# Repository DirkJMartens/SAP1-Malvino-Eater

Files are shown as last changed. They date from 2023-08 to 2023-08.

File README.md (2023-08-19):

# SAP1-Malvino-Eater
Wire wrapped implementation of Albert Malvino's SAP1 computer, similar to Ben Eater's "8 bit CPU". 

Like thousands of others, I watched Ben Eater's YouTube series on how to "Build an 8-bit CPU from scratch". 
Ben's video series is based on the "SAP-1 (Simple As Possible 1)" computer, described in "Digital Computer Electronics" 
book by Albert Malvino and Jerald Brown, first released in 1977. 

And like thousands of others, I wanted to build my own. Partly to learn a few things, but above all for fun. 
But I also wanted a few differences: 
  - Use wire-wrapping instead of breadboards. As I could only work on it mostly on weekends and in my spare time,
    I wanted it to be longer-lasting so I could put it away easily and pull it out without first spending time to
    find which wires have been dislodged to get it back working again. 
  - Stay closer to Malvino's original design for the SAP-1. 
  - Add some blinkenlights to visualize:
    - LED bar graphs for W-bus, Accu, B-register, Output-register, Instruction register 
    - LEDs for the control signals (La, Ea, Lb, Eb, Ep, CE ...) and the Program Counter 
    - the ring counter indicating the stage of the Fetch/Execute cycle 
    - the instruction decoder 
  - Added a dual 7-segment display to visualize the W-bus content in HEX-format instead of in binary via LED bar graph.

In short, I wanted it to be much more of a visual CPU that can show which signal gets activated and what it triggers 
in various parts of the CPU. Because I wanted the wiring to be visible, I did not use wire-wrap sockets and wire on the 
bottom of the perfboard. Instead, I soldered pin headers next to each row of IC pins so I had access to each pin on the 
top and wire-wrapped from pinheader pin to pinheader pin. 

Most important specs: 
  - 4 bits address bus with 16 bytes RAM memory and an 8 bits data bus 
  - 4 instructions: Load, Add, Sub and Out
  - Opcodes is the most-significant-nibble (top 4 bits) and memory location is the least (bottom 4 bits) 
  - Clock signal can be single stepped, or auto-run with variable clock speed (up to a few dozen Hz)
  - Done using a mix of various 74-series ICs (LS, F ...) and implemented on a 20cmx30cm (8"x12") perfboard.

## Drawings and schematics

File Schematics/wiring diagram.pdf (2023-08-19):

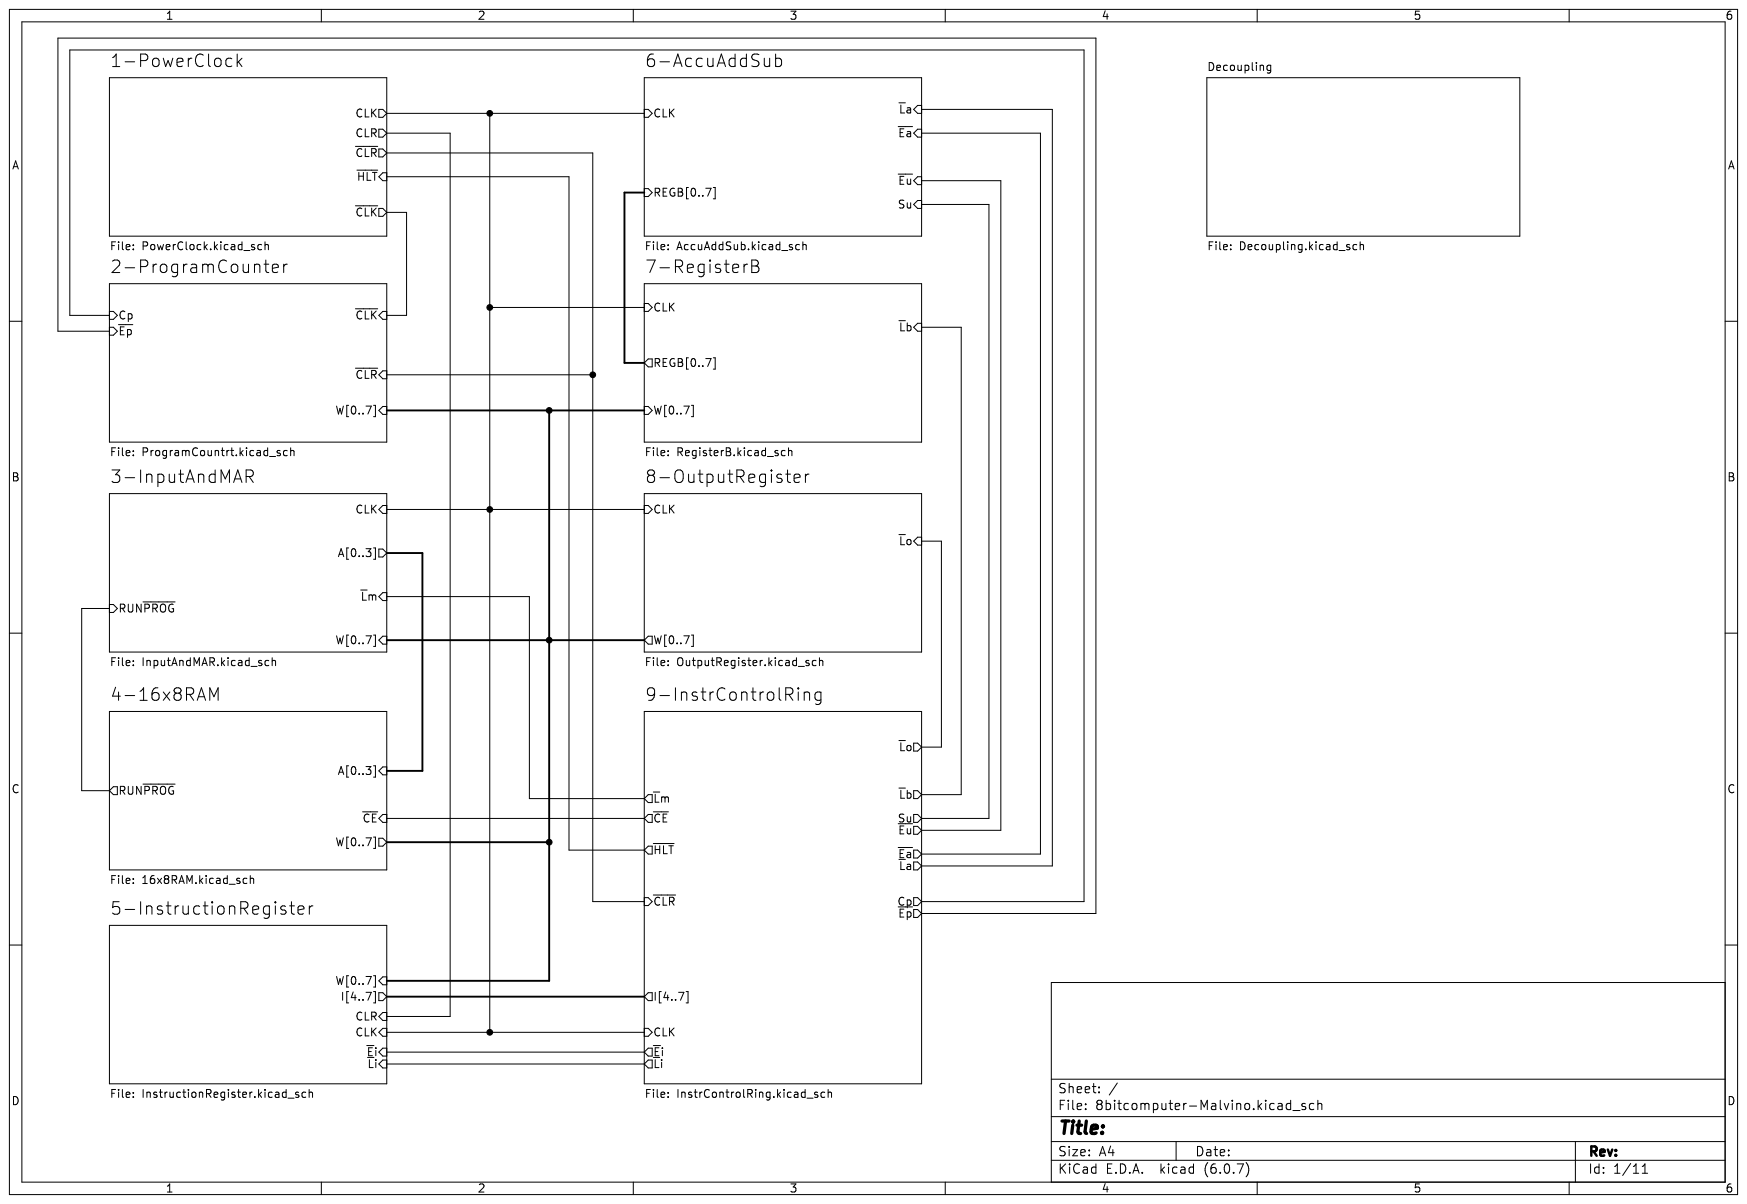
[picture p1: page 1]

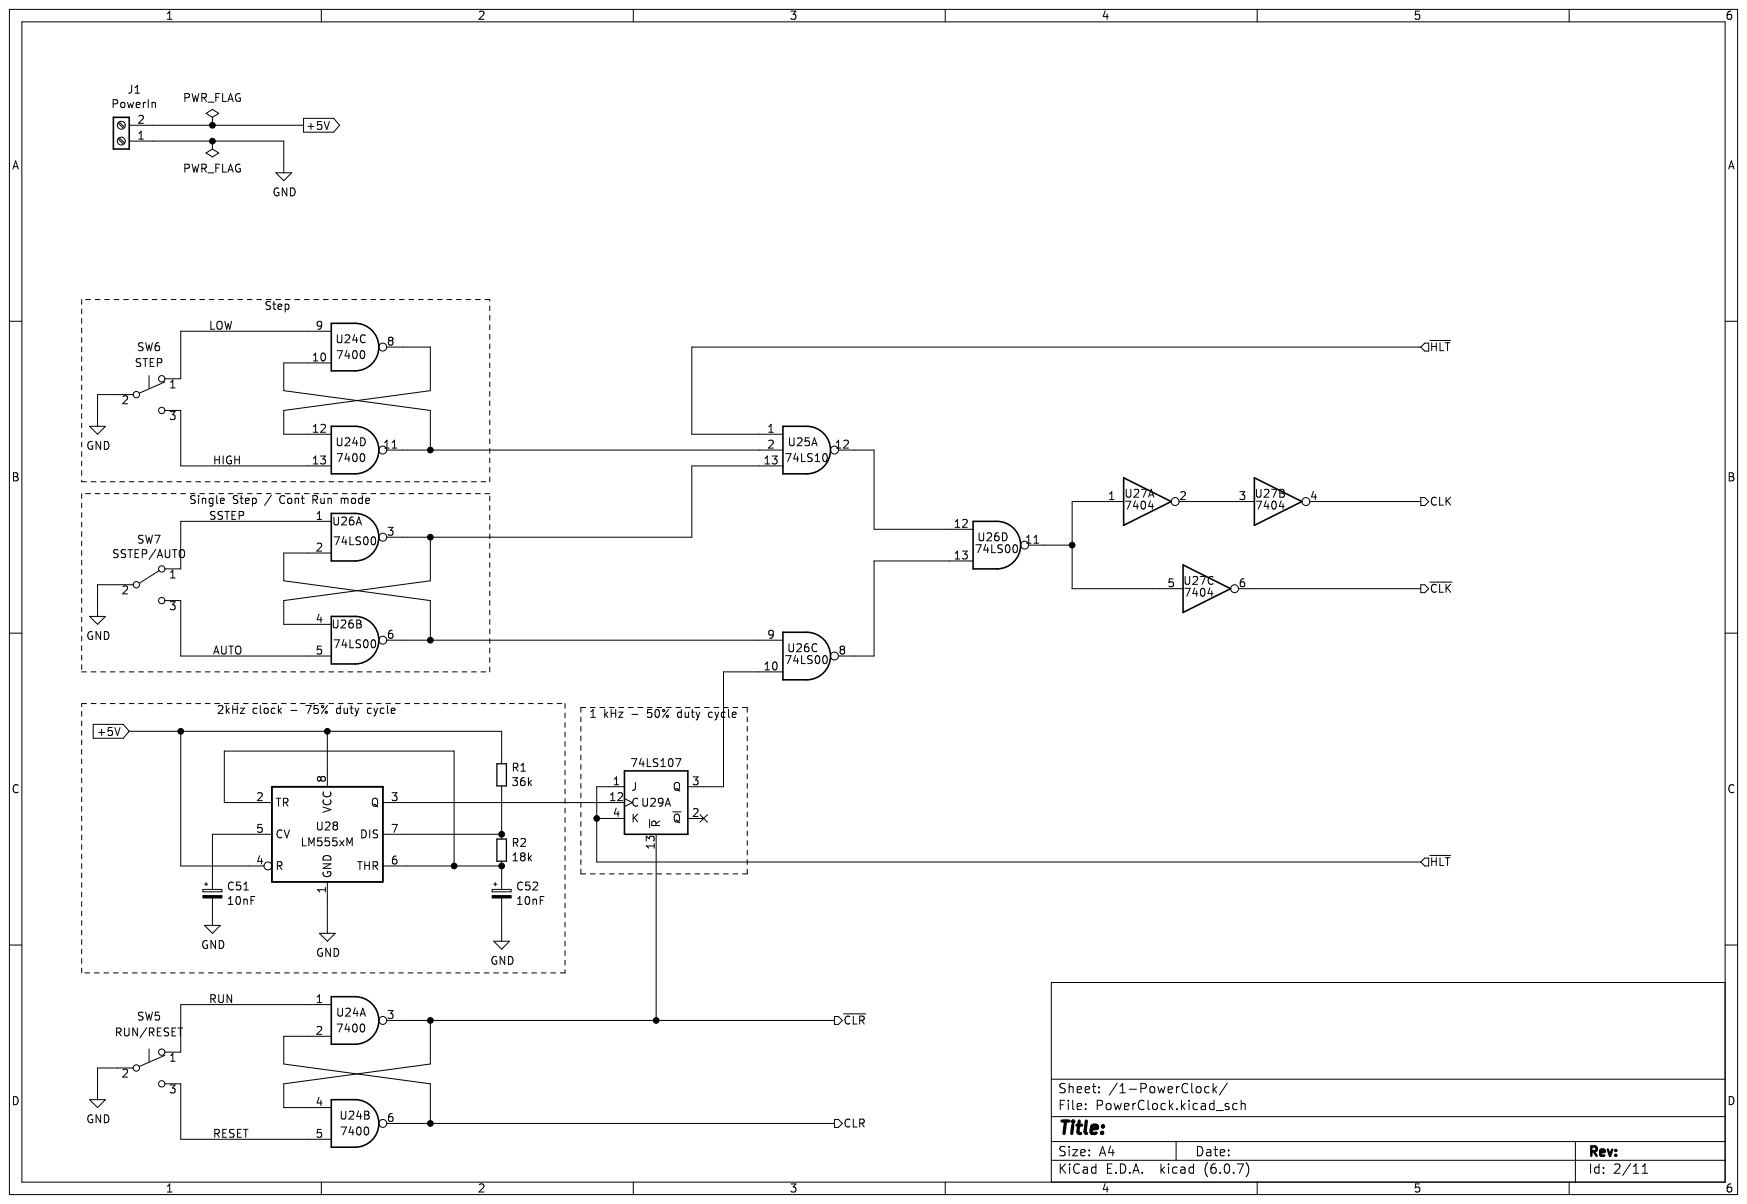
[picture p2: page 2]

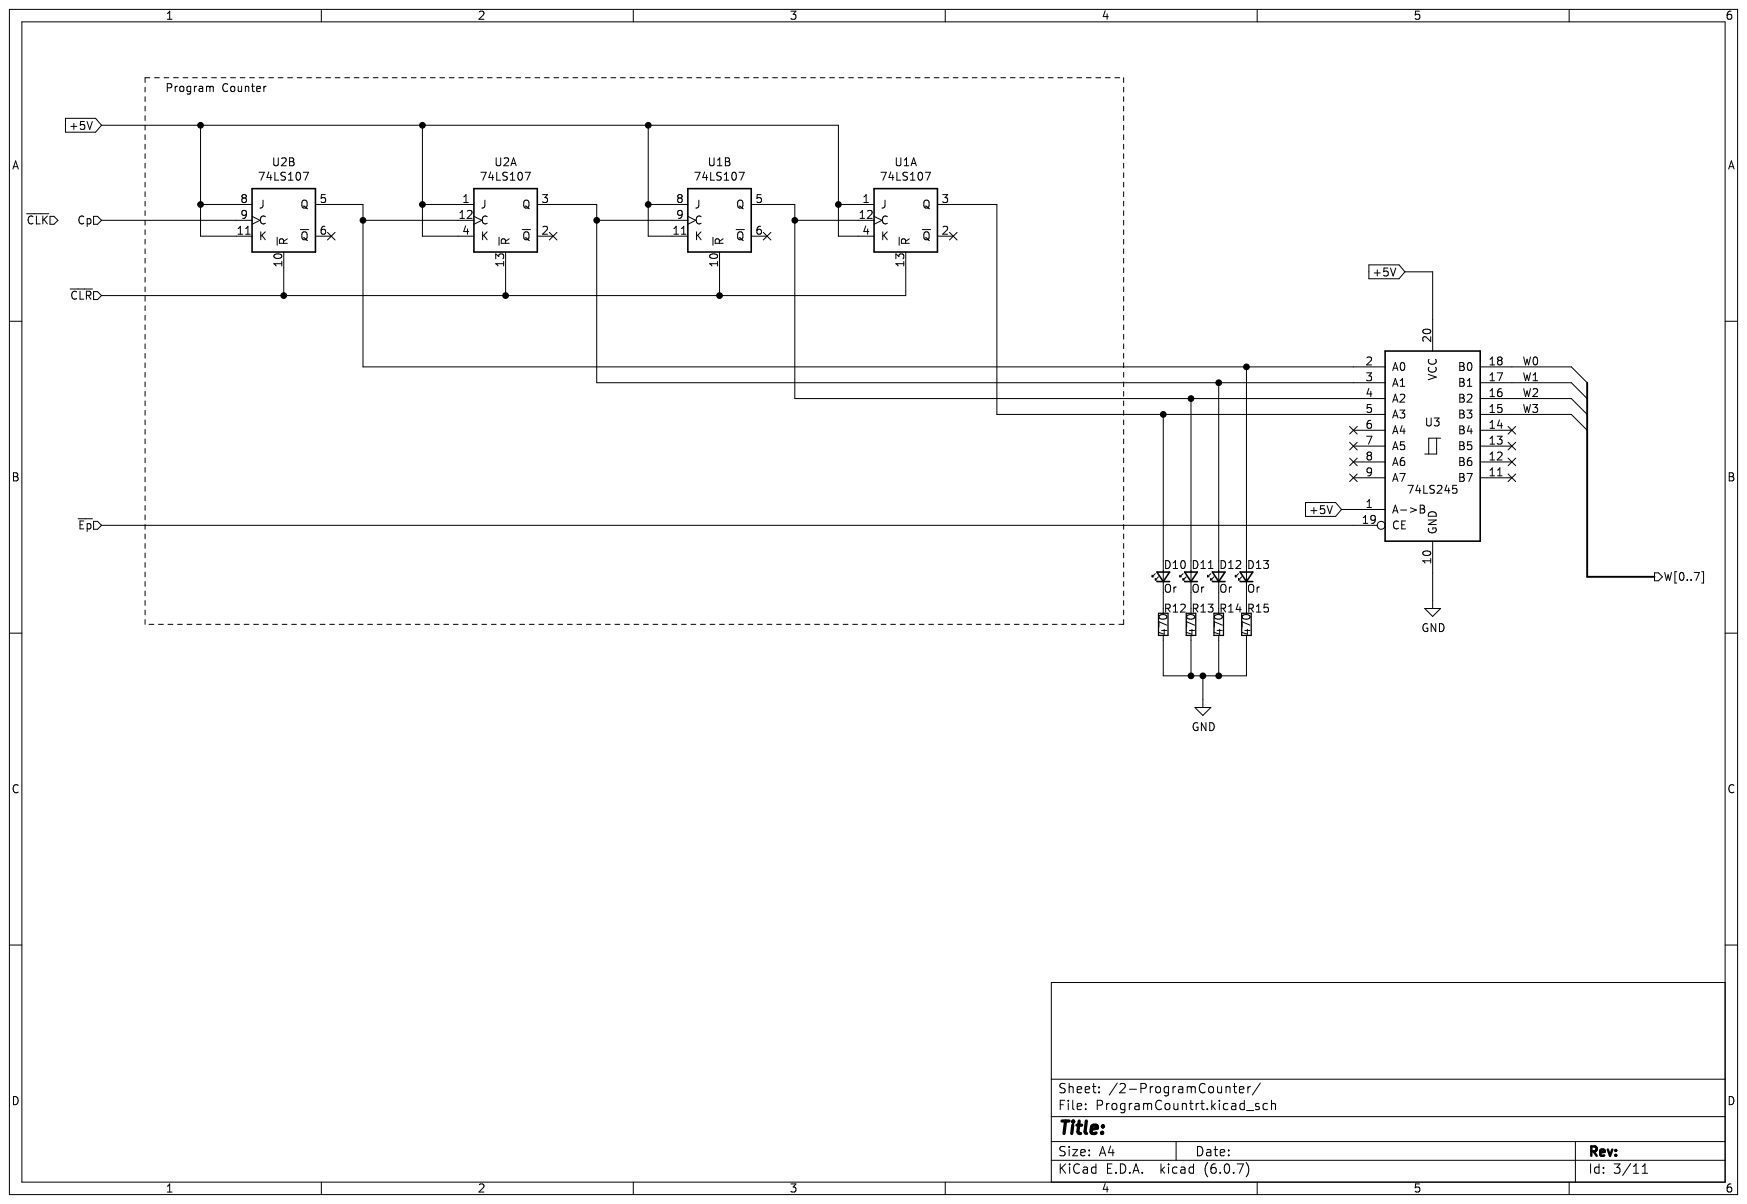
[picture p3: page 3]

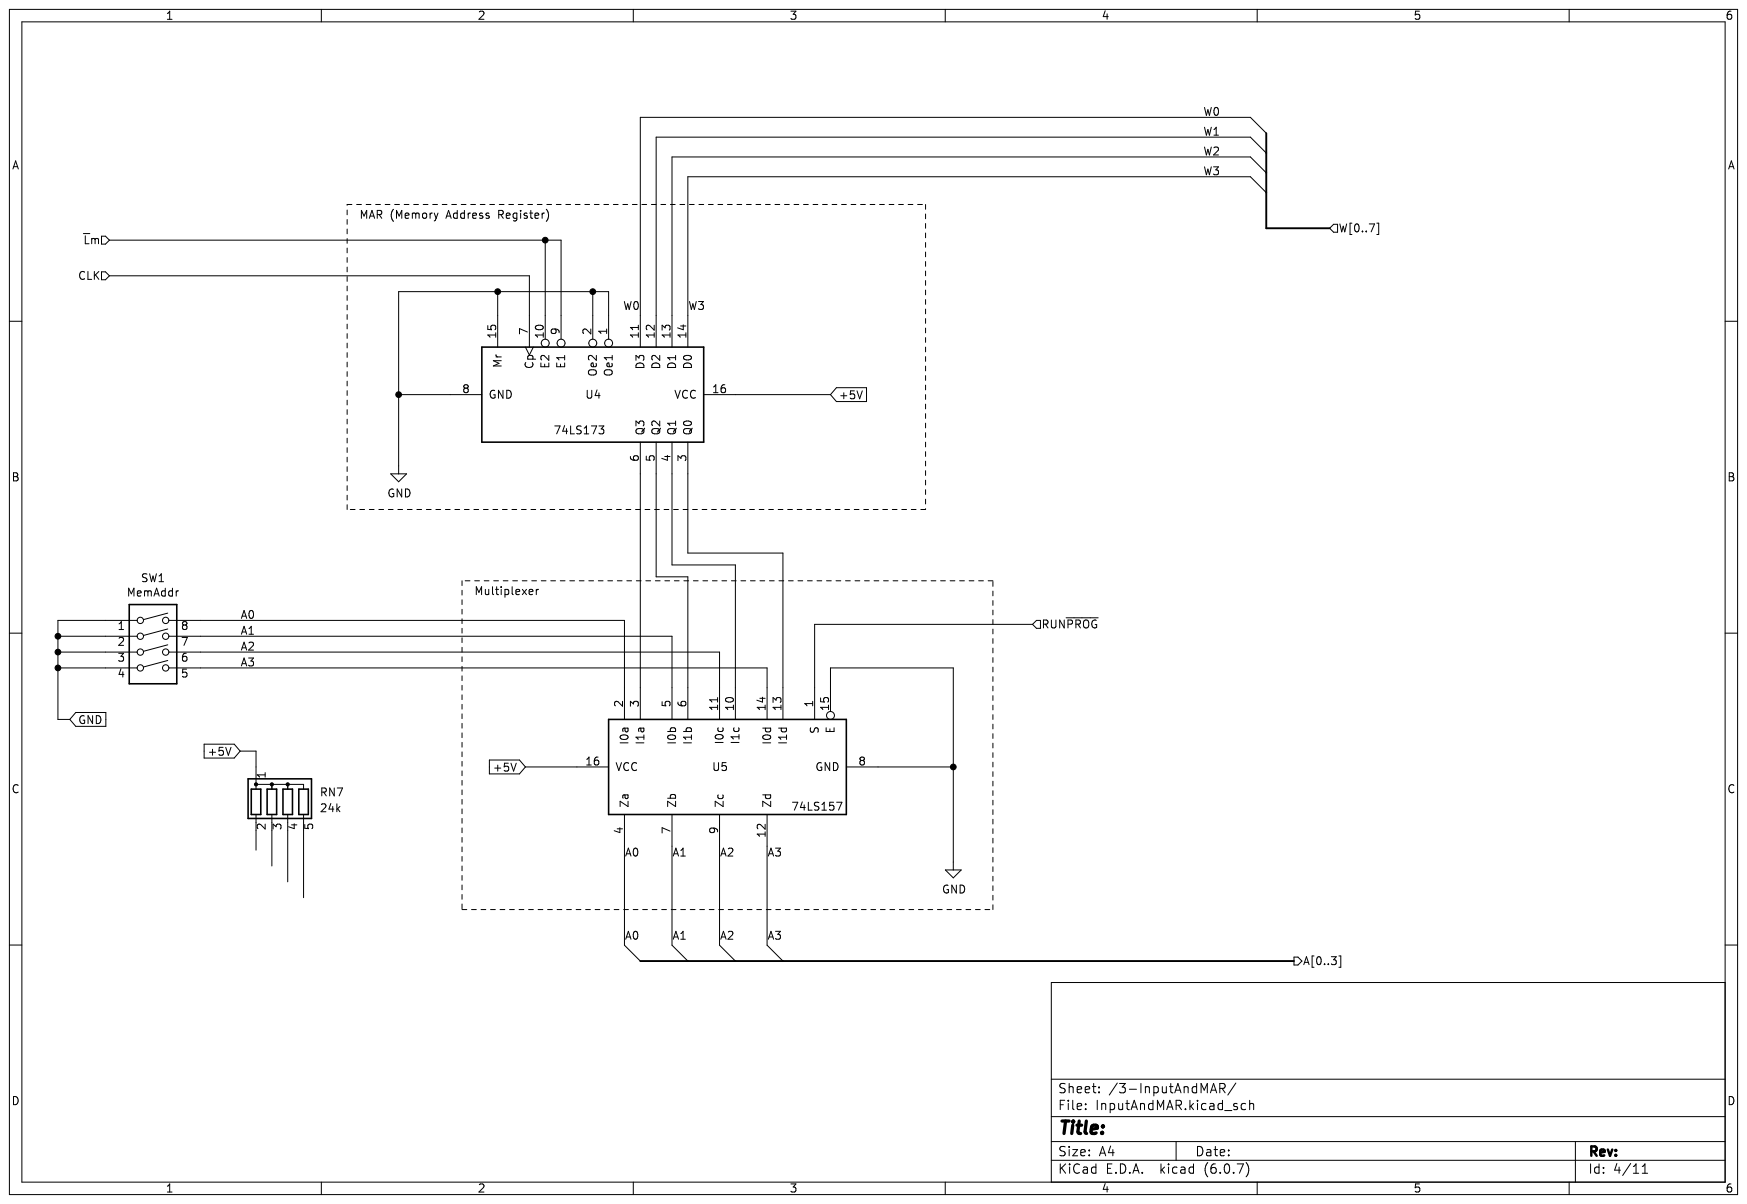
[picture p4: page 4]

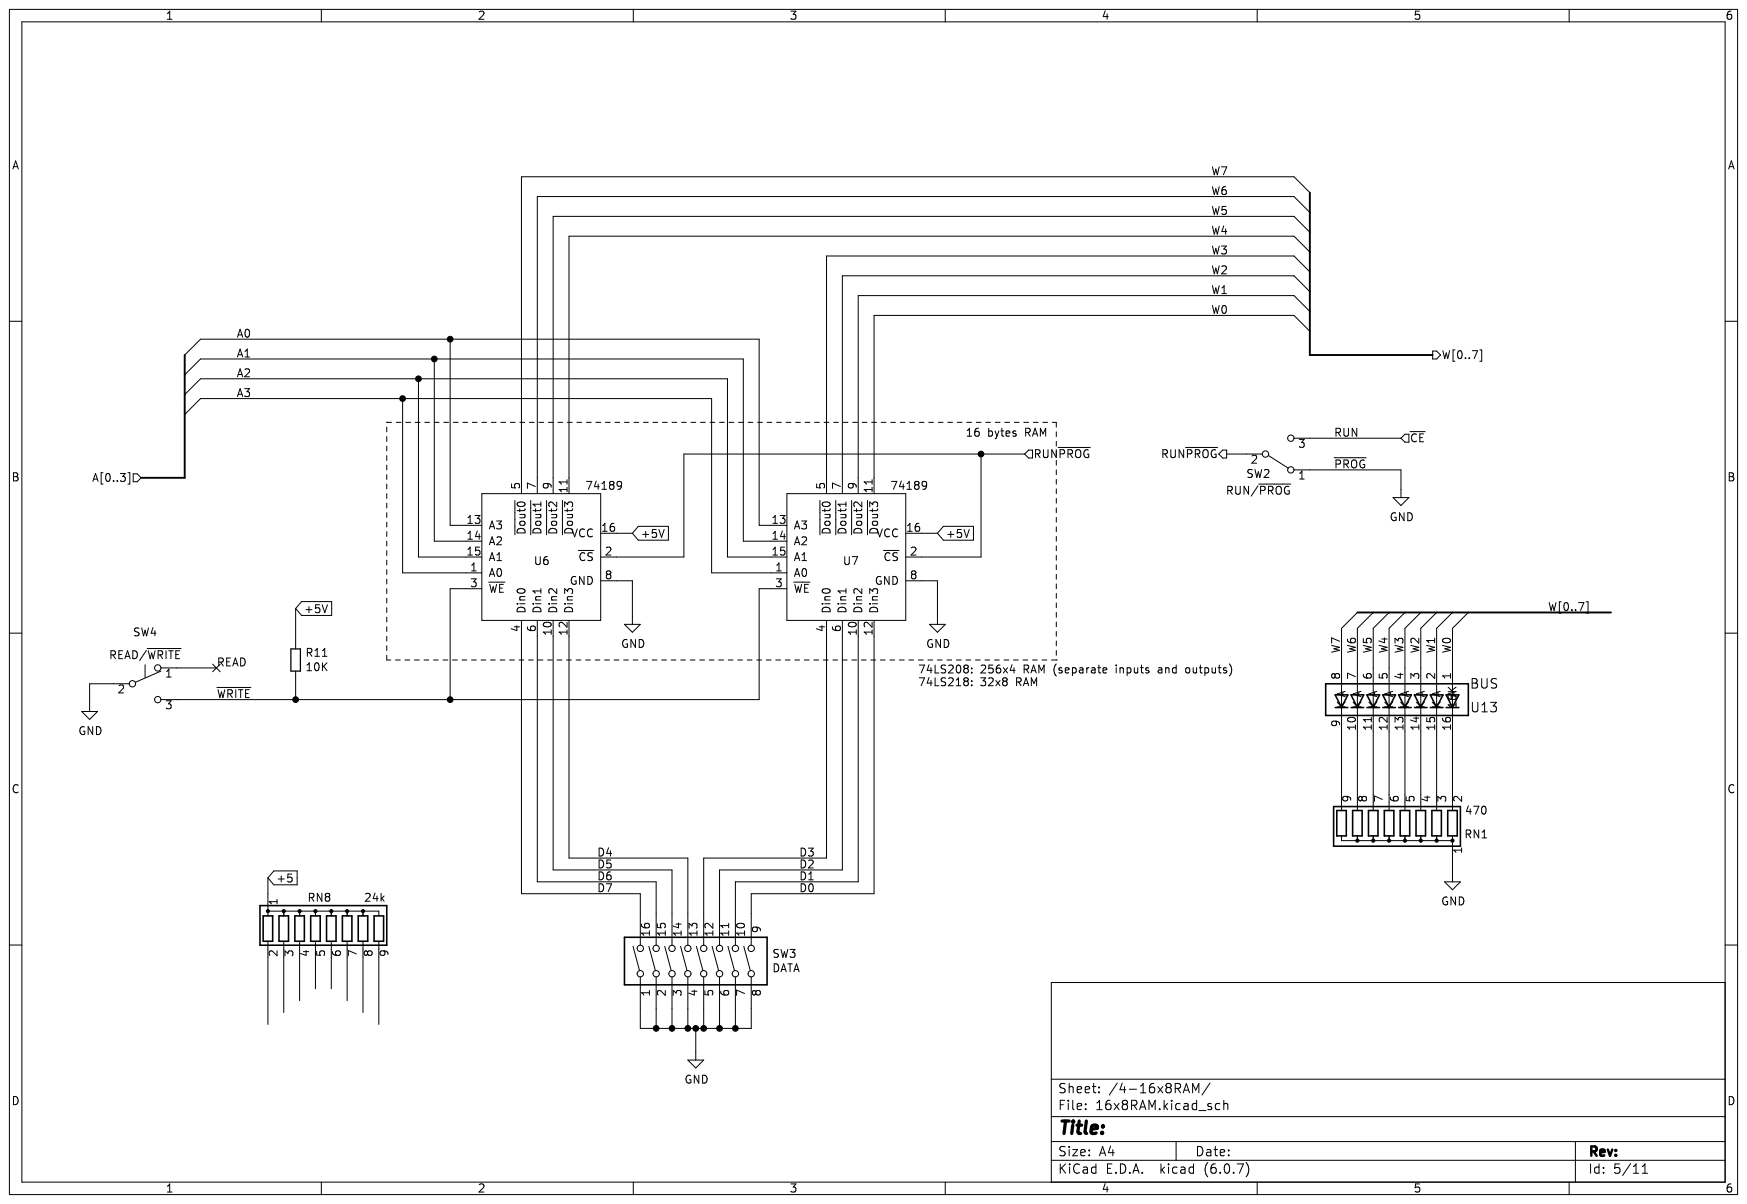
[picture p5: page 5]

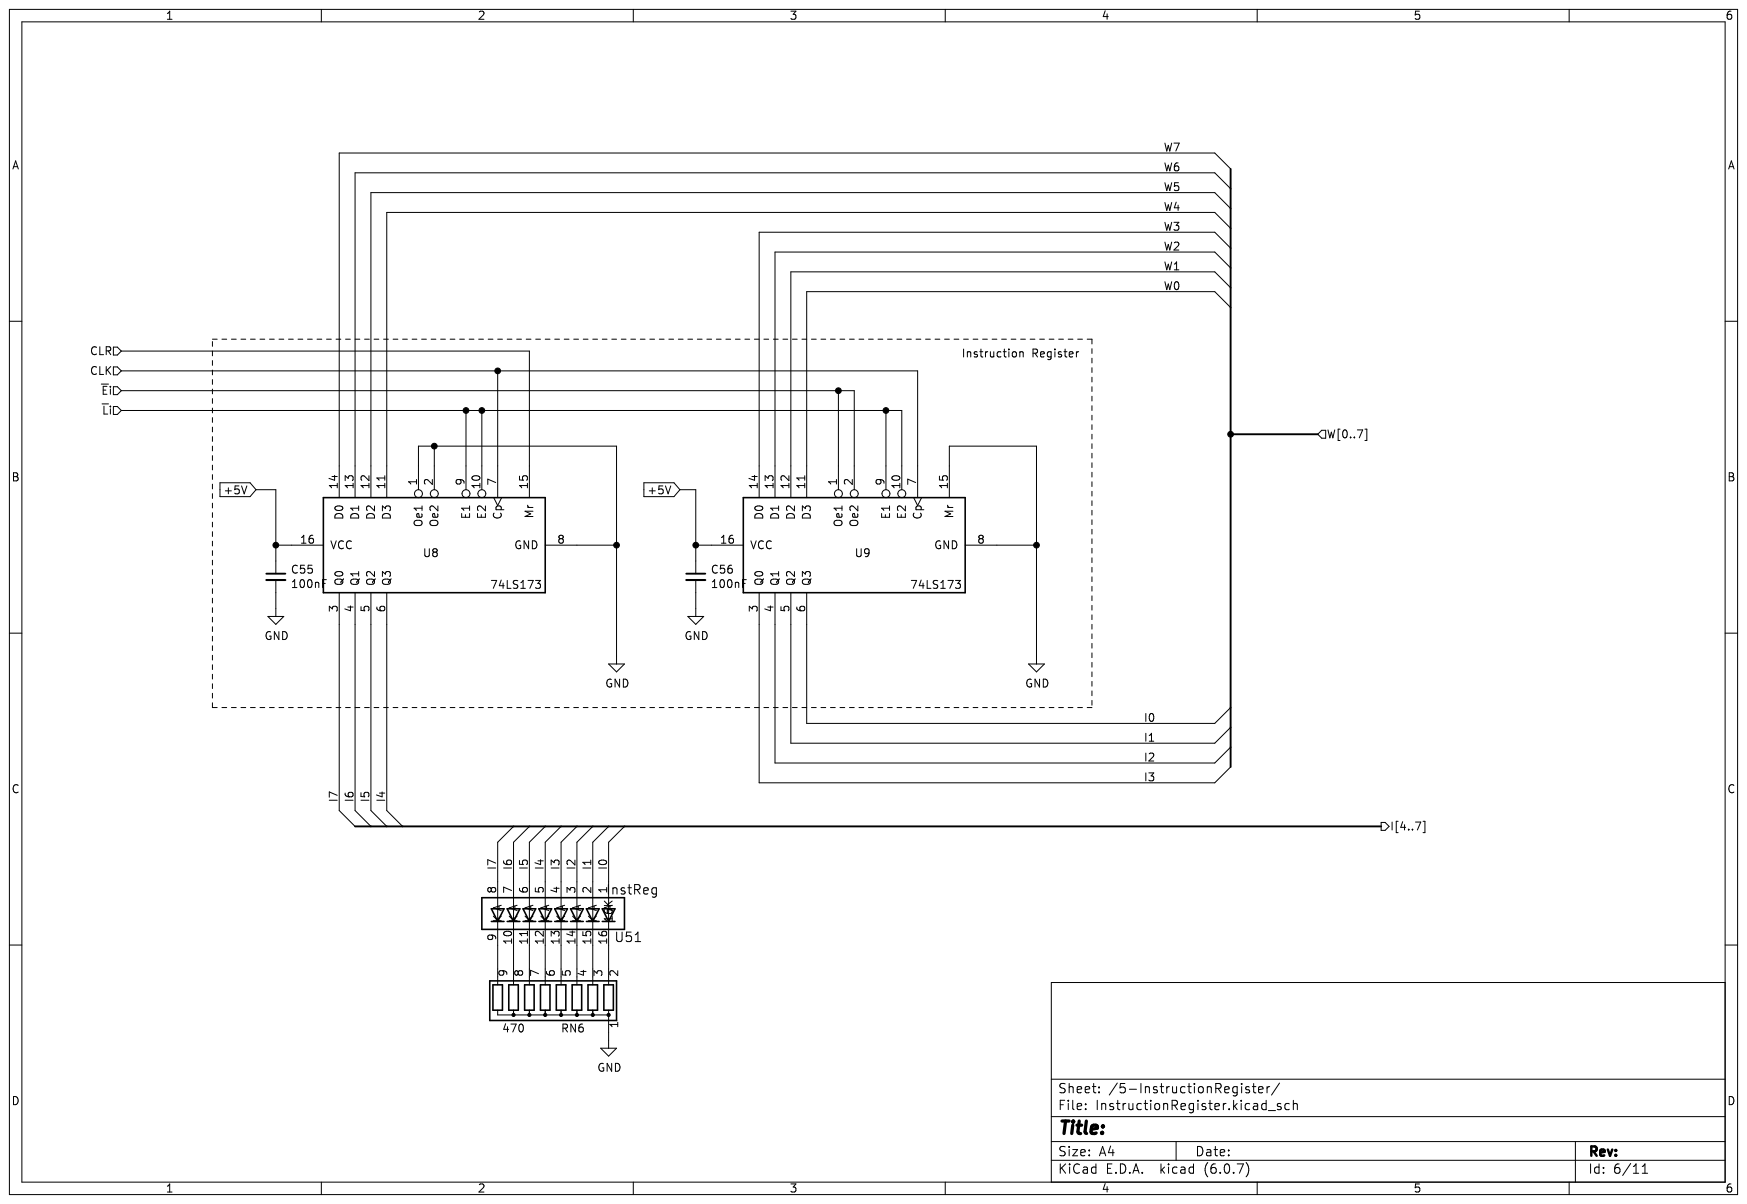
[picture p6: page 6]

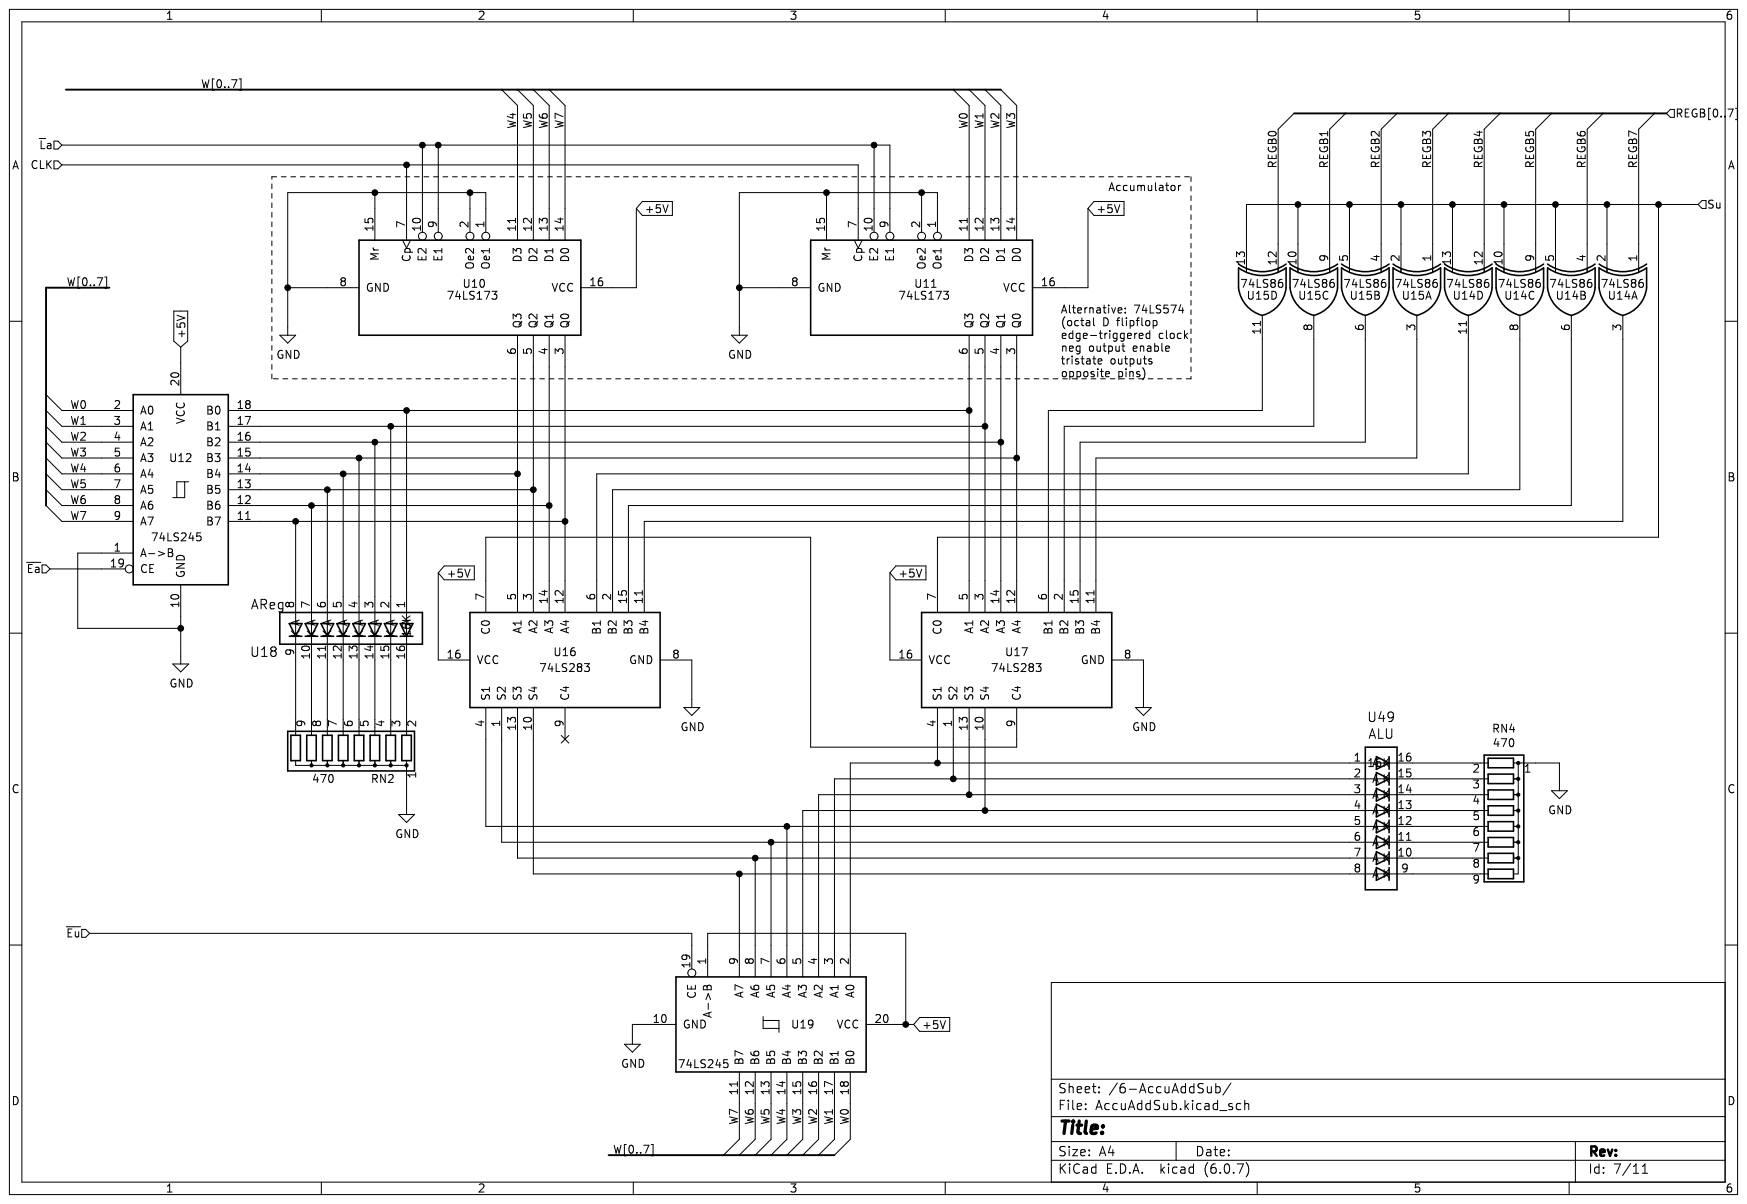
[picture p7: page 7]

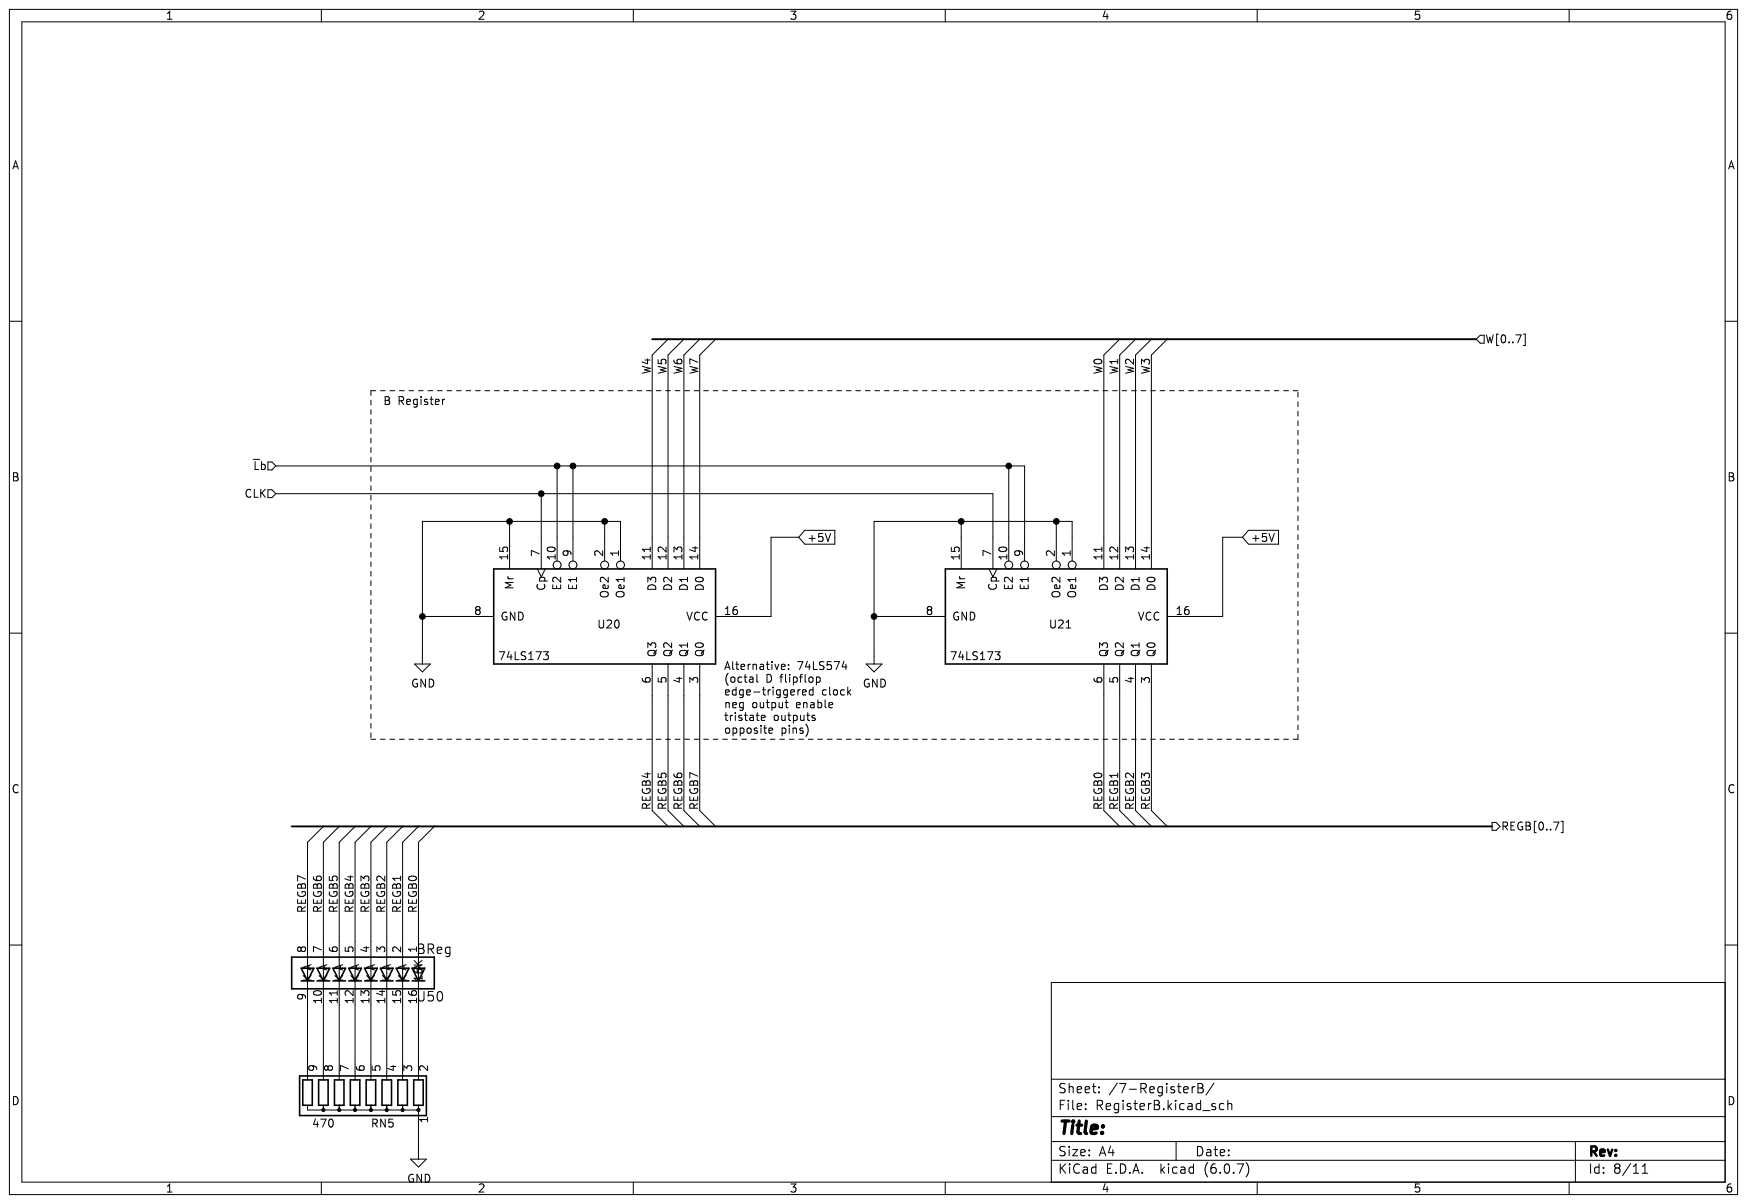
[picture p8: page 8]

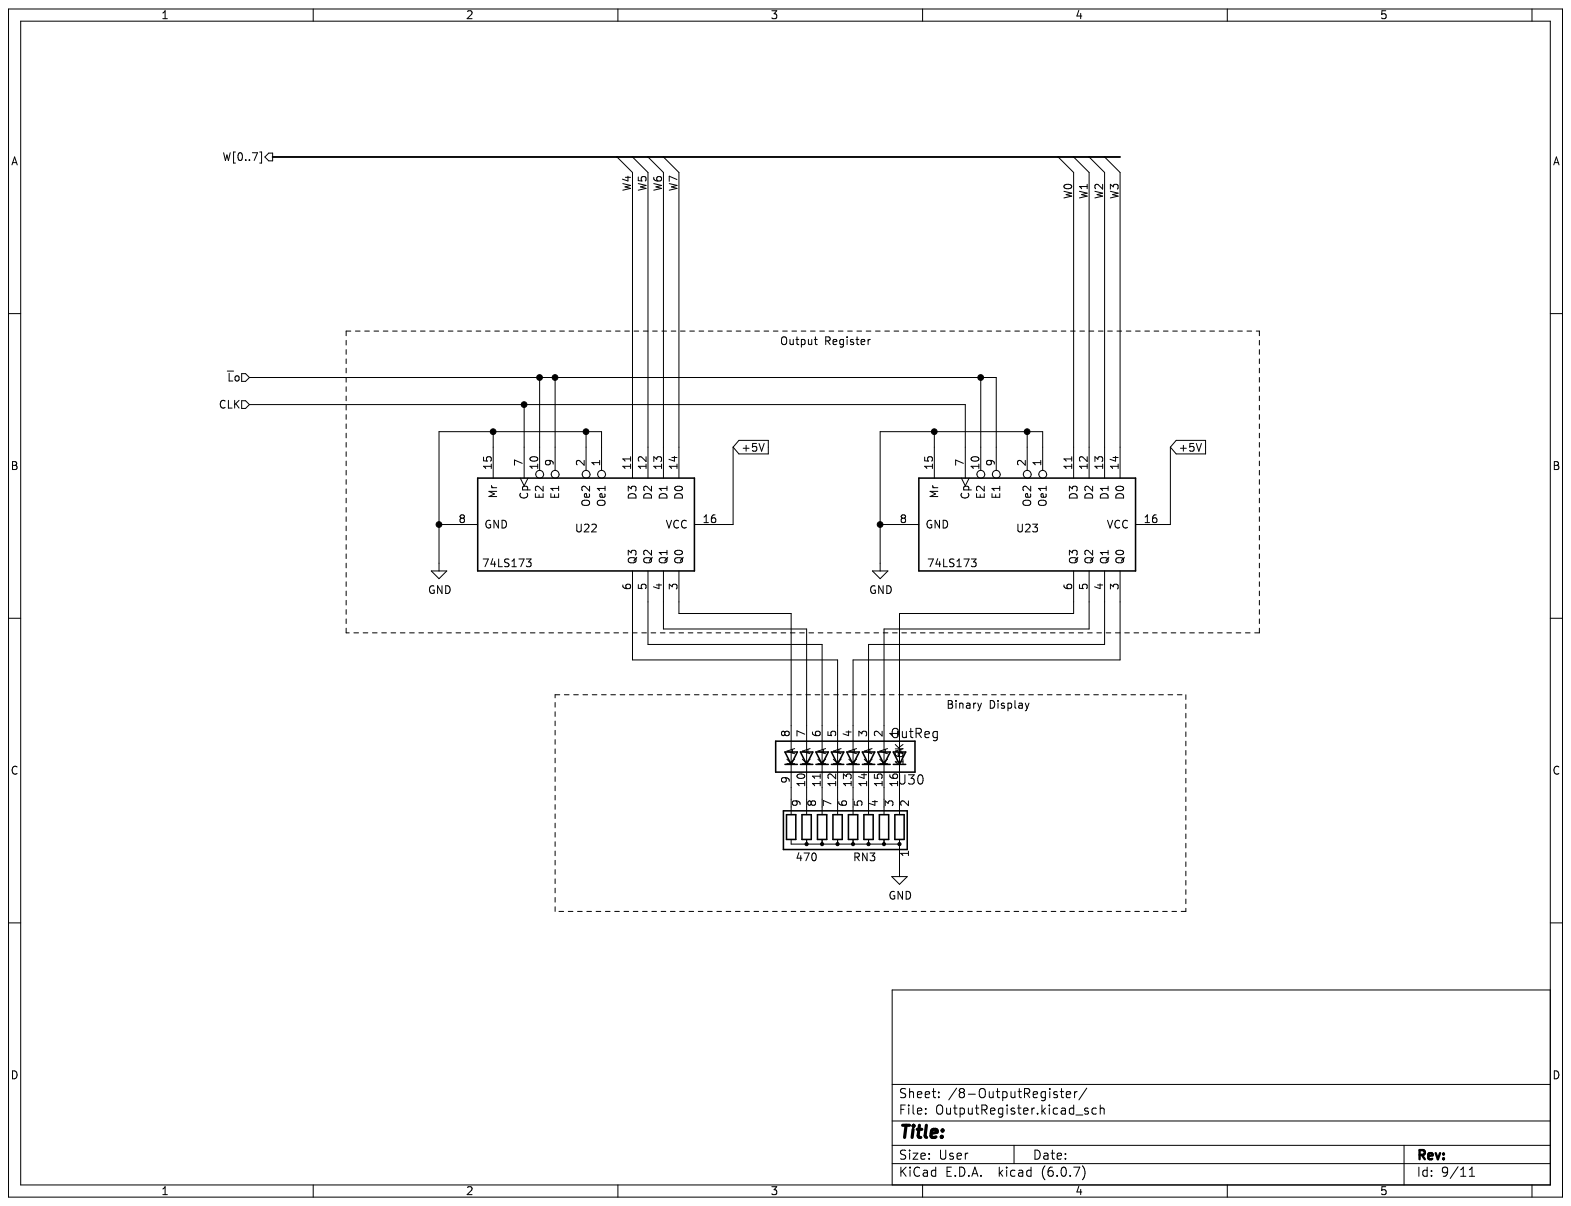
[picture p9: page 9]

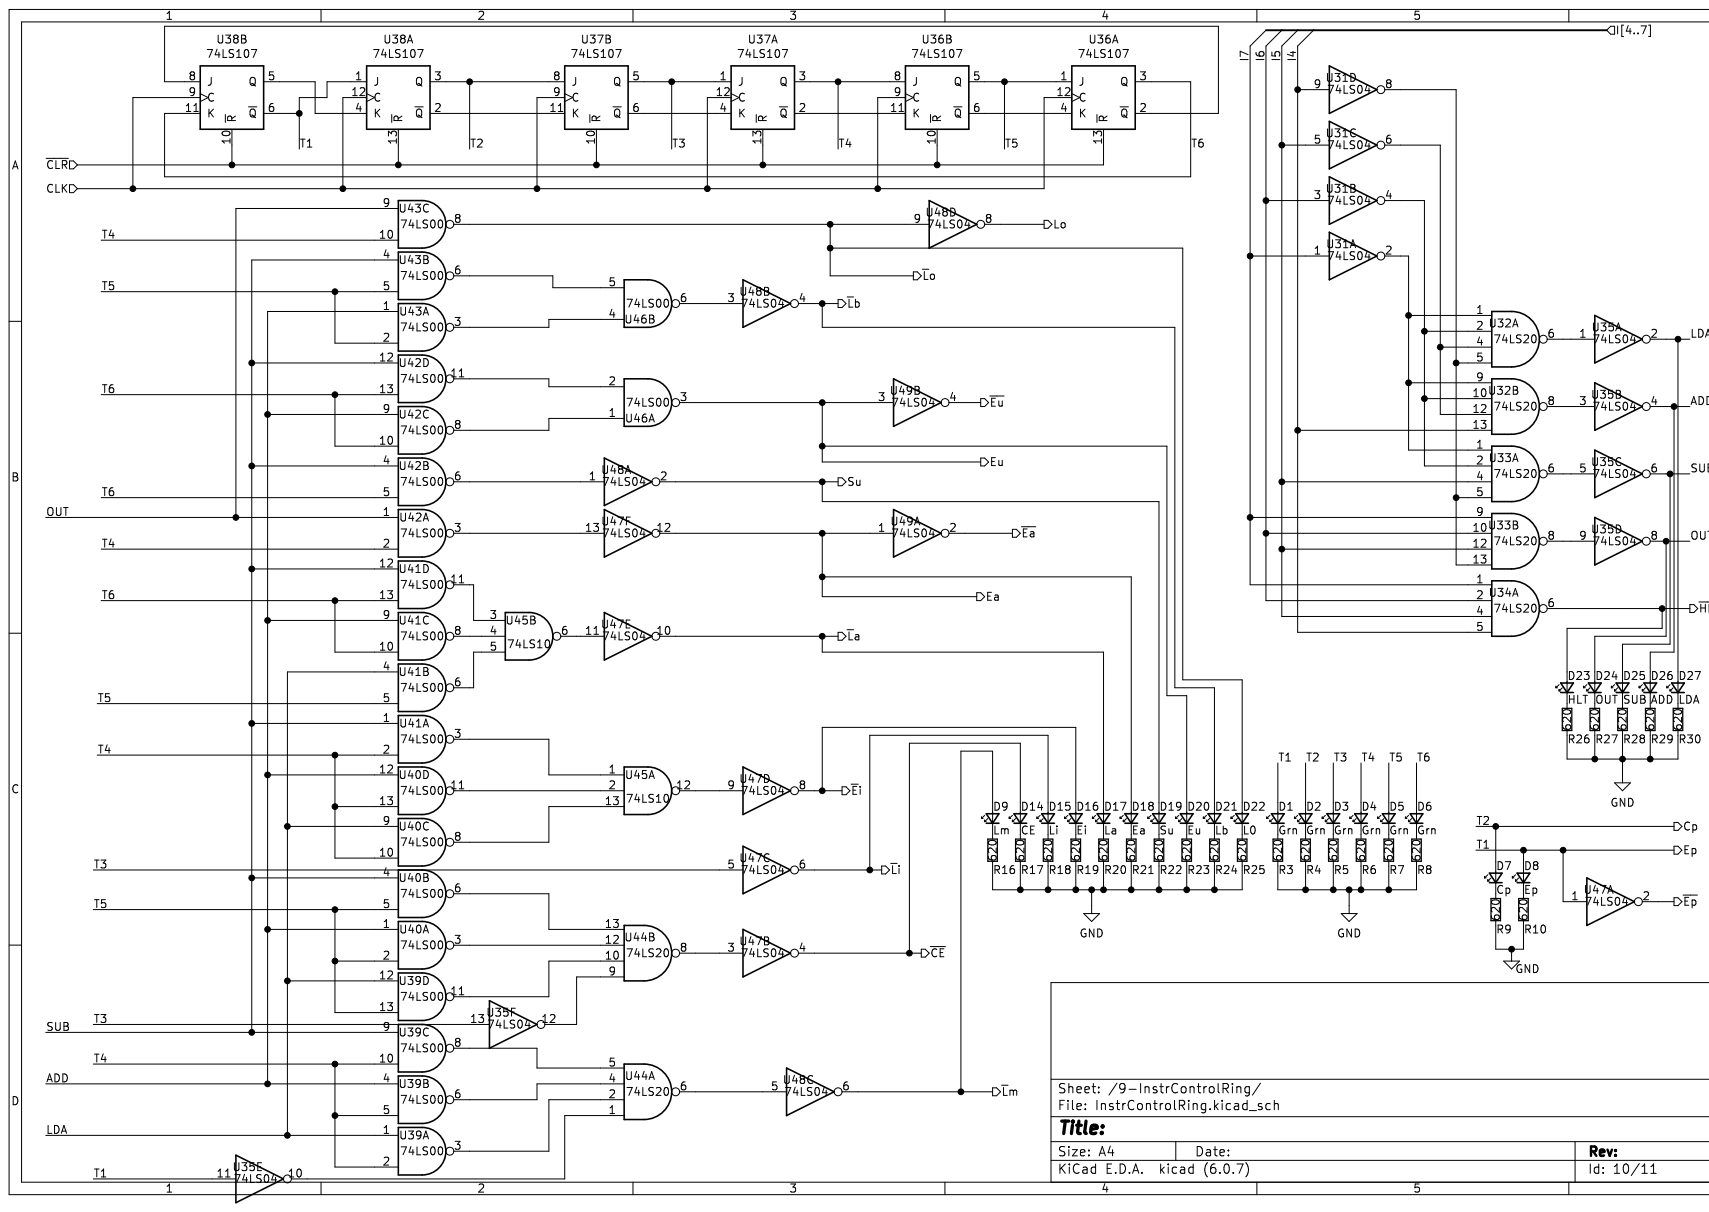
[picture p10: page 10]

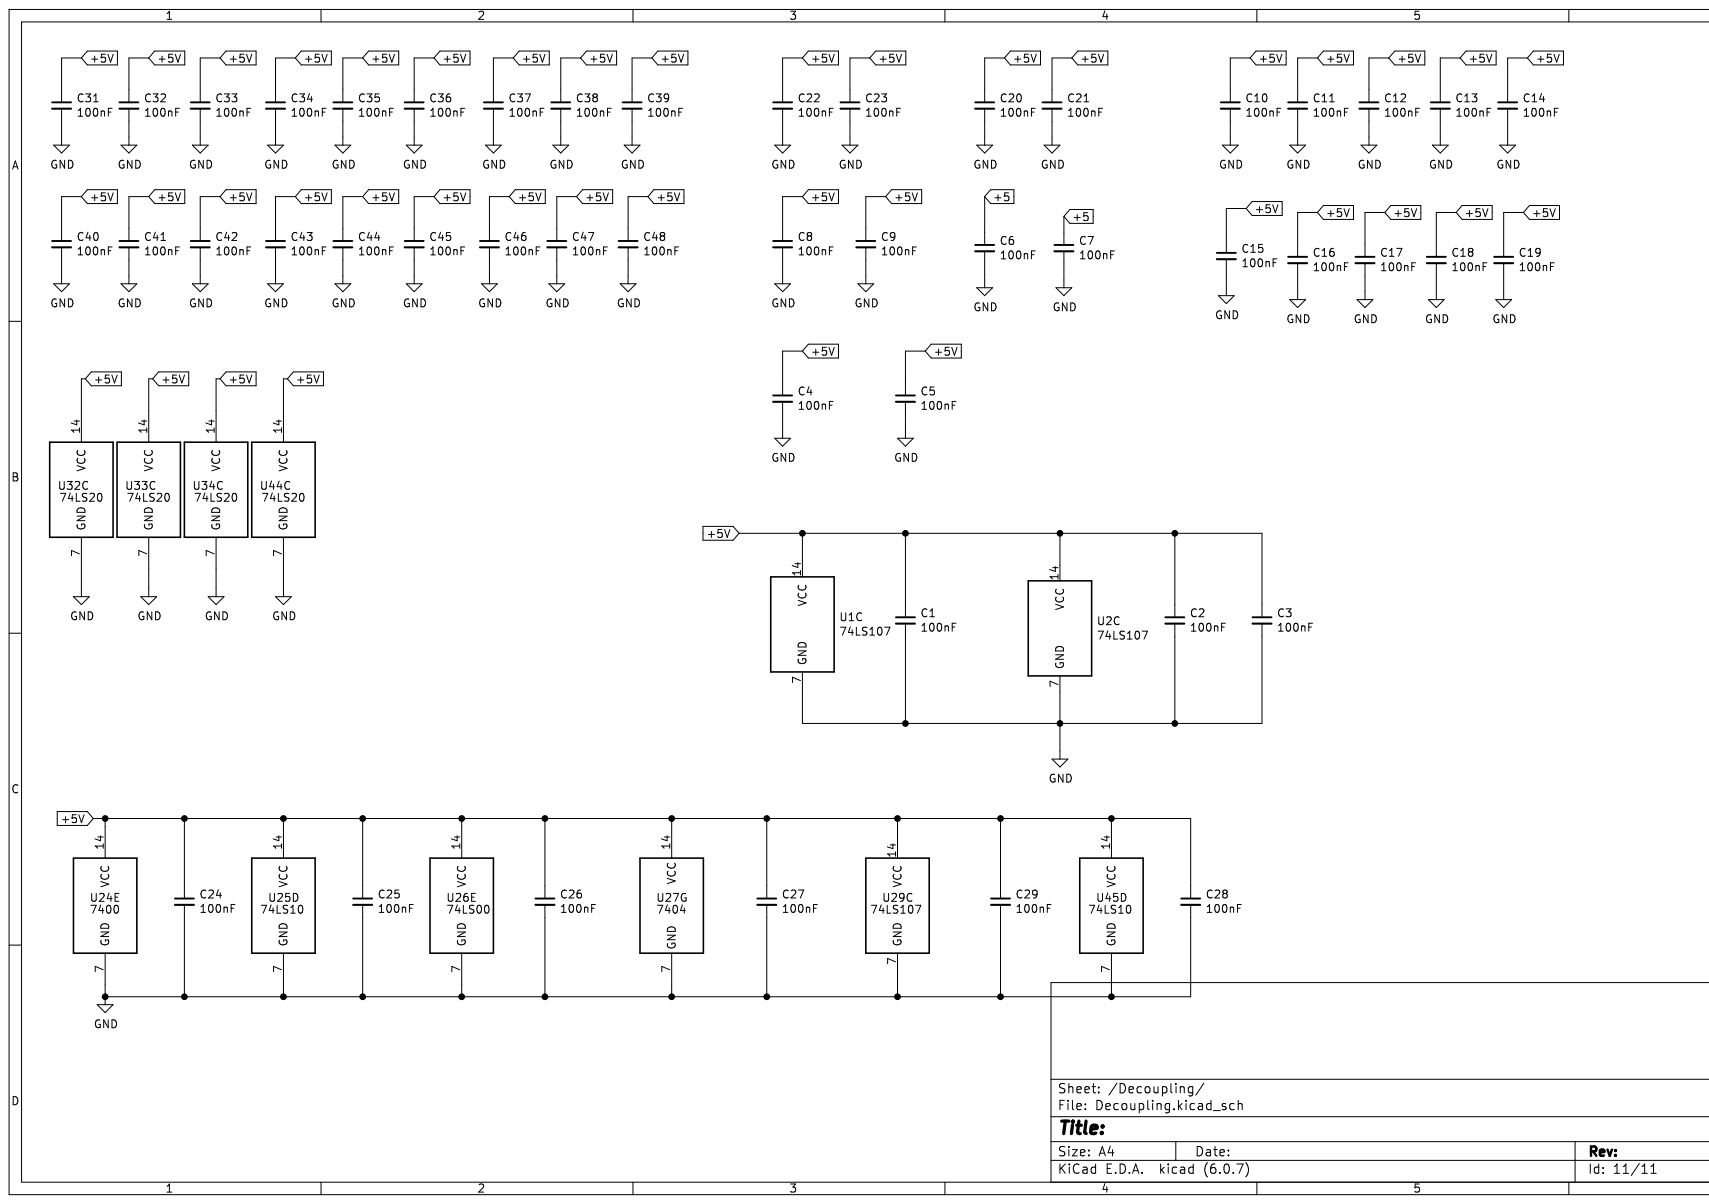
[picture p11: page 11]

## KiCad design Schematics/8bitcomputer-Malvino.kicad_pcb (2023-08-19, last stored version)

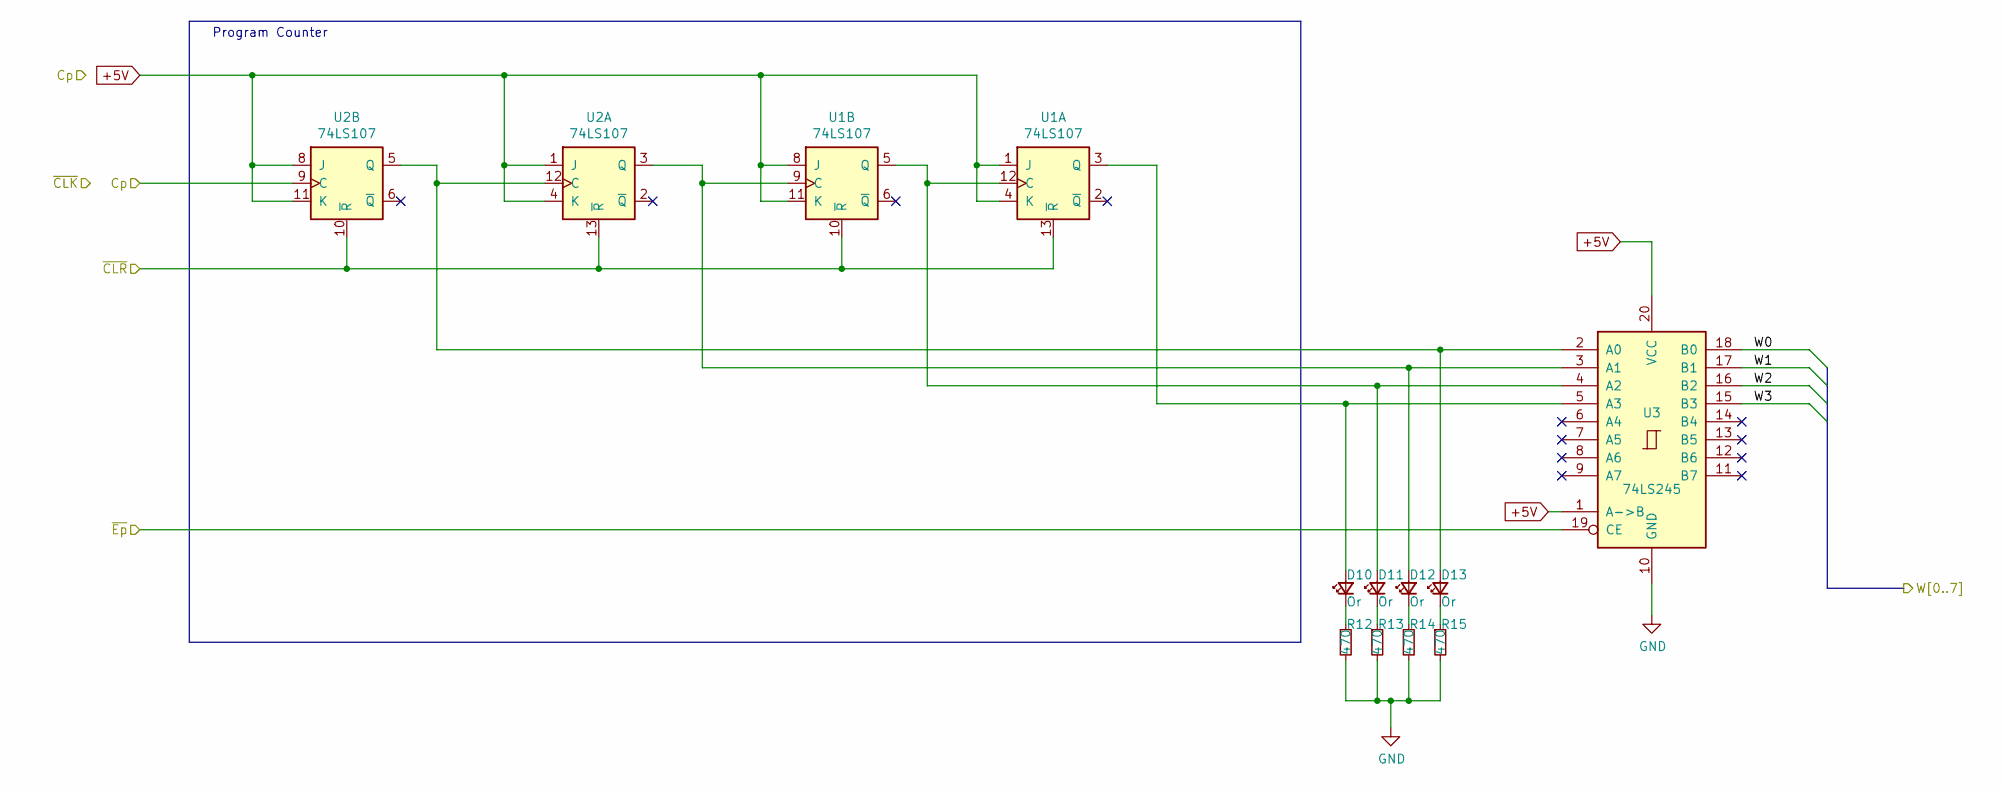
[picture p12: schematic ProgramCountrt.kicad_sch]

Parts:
D10, D11, D12, D13: Or; LED_D3.0mm
R12, R13, R14, R15: 470; R_0805_2012Metric
U1, U2: 74LS107; DIP-14_W7.62mm_LongPads
U3: 74LS245; DIP-20_W7.62mm_LongPads

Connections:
+5V: U1.1 (J), U1.4 (K), U1.8 (J), U1.11 (K), U2.1 (J), U2.4 (K), U2.8 (J), U2.11 (K), U3.1 (A->B), U3.20 (VCC); also elsewhere on the board
/1-PowerClock/~CLR: U1.10 (~R), U1.13 (~R), U2.10 (~R), U2.13 (~R); also elsewhere on the board
/2-ProgramCounter/~Ep: U3.19 (CE); also elsewhere on the board
/4-16x8RAM/W0: U3.18 (B0); also elsewhere on the board
/4-16x8RAM/W1: U3.17 (B1); also elsewhere on the board
/4-16x8RAM/W2: U3.16 (B2); also elsewhere on the board
/4-16x8RAM/W3: U3.15 (B3); also elsewhere on the board
/9-InstrControlRing/T2: U2.9 (C); also elsewhere on the board
GND: R12.2, R13.2, R14.2, R15.2, U3.10 (GND); also elsewhere on the board
unnamed: D10.1 (K), R12.1
unnamed: D10.2 (A), U1.3 (Q), U3.5 (A3)
unnamed: D11.1 (K), R13.1
unnamed: D11.2 (A), U1.5 (Q), U1.12 (C), U3.4 (A2)
unnamed: D12.1 (K), R14.1
unnamed: D12.2 (A), U1.9 (C), U2.3 (Q), U3.3 (A1)
unnamed: D13.1 (K), R15.1
unnamed: D13.2 (A), U2.5 (Q), U2.12 (C), U3.2 (A0)

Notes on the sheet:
Program Counter

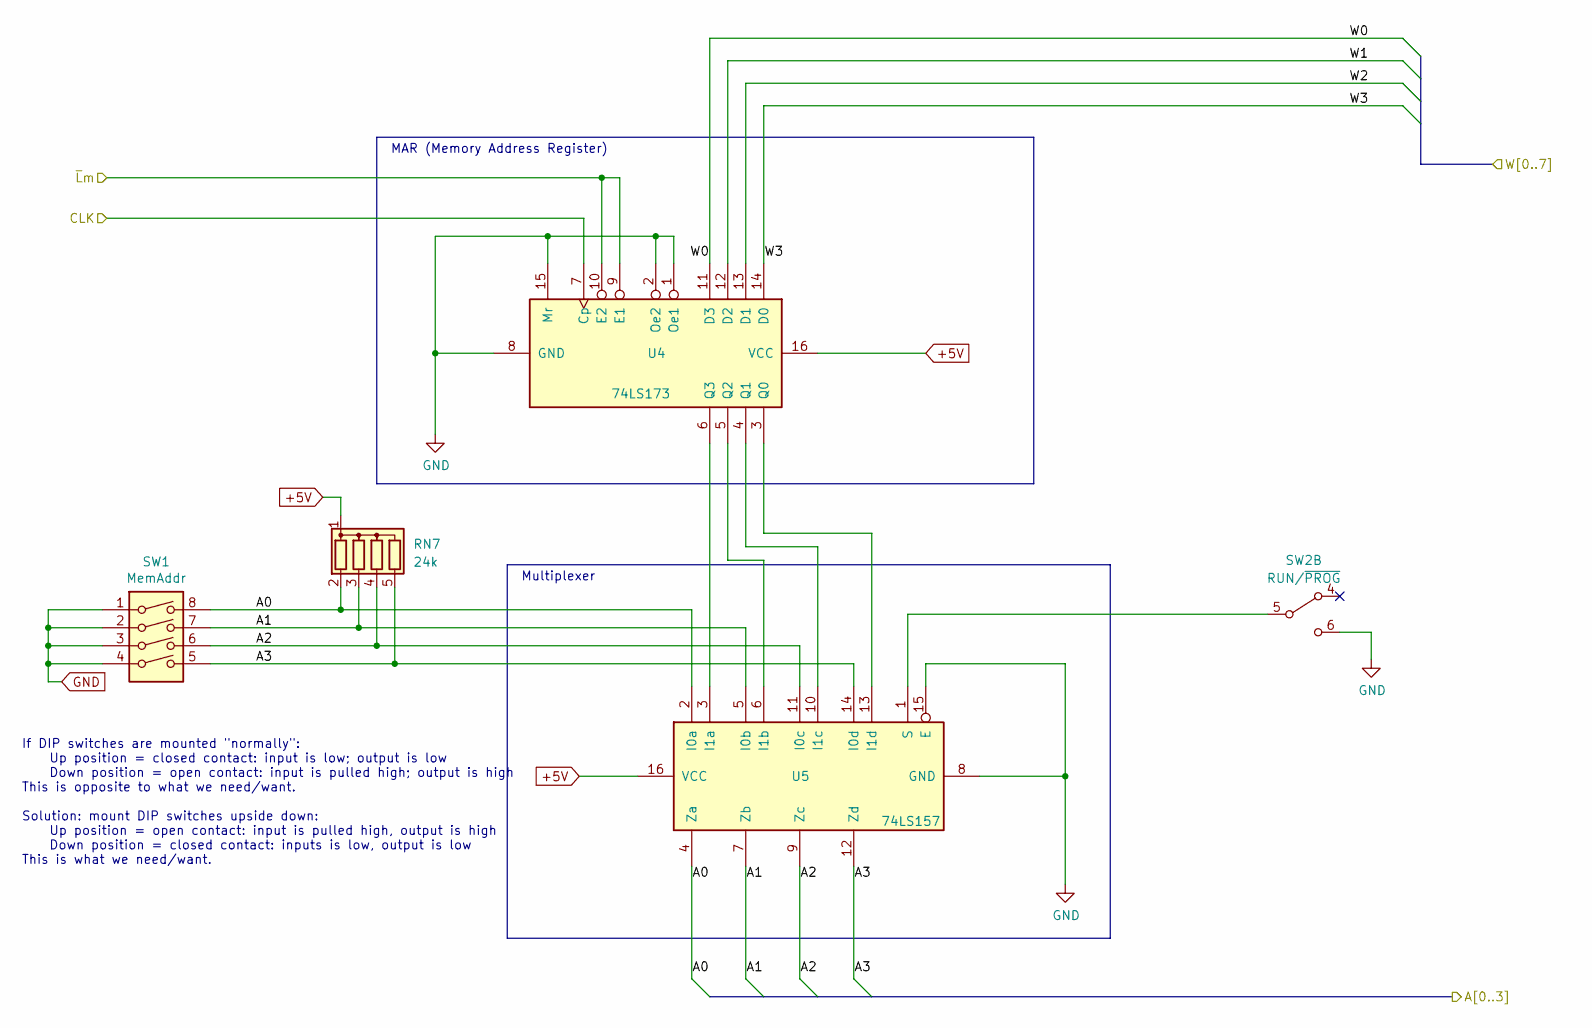
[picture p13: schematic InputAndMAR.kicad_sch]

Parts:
RN7: 24k; R_Array_SIP5
SW1: MemAddr; SW_DIP_SPSTx04_Slide_9.78x12.34mm_W7.62mm_P2.54mm
SW2: RUN/~{PROG}; SW_CuK_JS202011AQN_DPDT_Angled
U4: 74LS173; DIP-16_W7.62mm_LongPads
U5: 74LS157; DIP-16_W7.62mm_LongPads

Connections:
+5V: RN7.1 (common), U4.16 (VCC), U5.16 (VCC); also elsewhere on the board
/1-PowerClock/CLK: U4.7 (Cp); also elsewhere on the board
/3-InputAndMAR/A0: RN7.2 (R1), SW1.8, U5.2 (I0a), U5.4 (Za); also elsewhere on the board
/3-InputAndMAR/A1: RN7.3 (R2), SW1.7, U5.5 (I0b), U5.7 (Zb); also elsewhere on the board
/3-InputAndMAR/A2: RN7.4 (R3), SW1.6, U5.9 (Zc), U5.11 (I0c); also elsewhere on the board
/3-InputAndMAR/A3: RN7.5 (R4), SW1.5, U5.12 (Zd), U5.14 (I0d); also elsewhere on the board
/3-InputAndMAR/~Lm: U4.9 (E1), U4.10 (E2); also elsewhere on the board
/4-16x8RAM/W0: U4.11 (D3); also elsewhere on the board
/4-16x8RAM/W1: U4.12 (D2); also elsewhere on the board
/4-16x8RAM/W2: U4.13 (D1); also elsewhere on the board
/4-16x8RAM/W3: U4.14 (D0); also elsewhere on the board
GND: SW1.1, SW1.2, SW1.3, SW1.4, SW2.6 (C), U4.1 (Oe1), U4.2 (Oe2), U4.8 (GND), U4.15 (Mr), U5.8 (GND), U5.15 (E); also elsewhere on the board
unnamed: U4.3 (Q0), U5.13 (I1d)
unnamed: U4.4 (Q1), U5.10 (I1c)
unnamed: U4.5 (Q2), U5.6 (I1b)
unnamed: U4.6 (Q3), U5.3 (I1a)
unnamed: SW2.5 (B), U5.1 (S)

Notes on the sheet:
Multiplexer
If DIP switches are mounted "normally": Up position = closed contact: input is low; output is low Down position = open contact: input is pulled high; output is high This is opposite to what we need/want. Solution: mount DIP switches upside down: Up position = open contact: input is pulled high, out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
MAR (Memory Address Register)

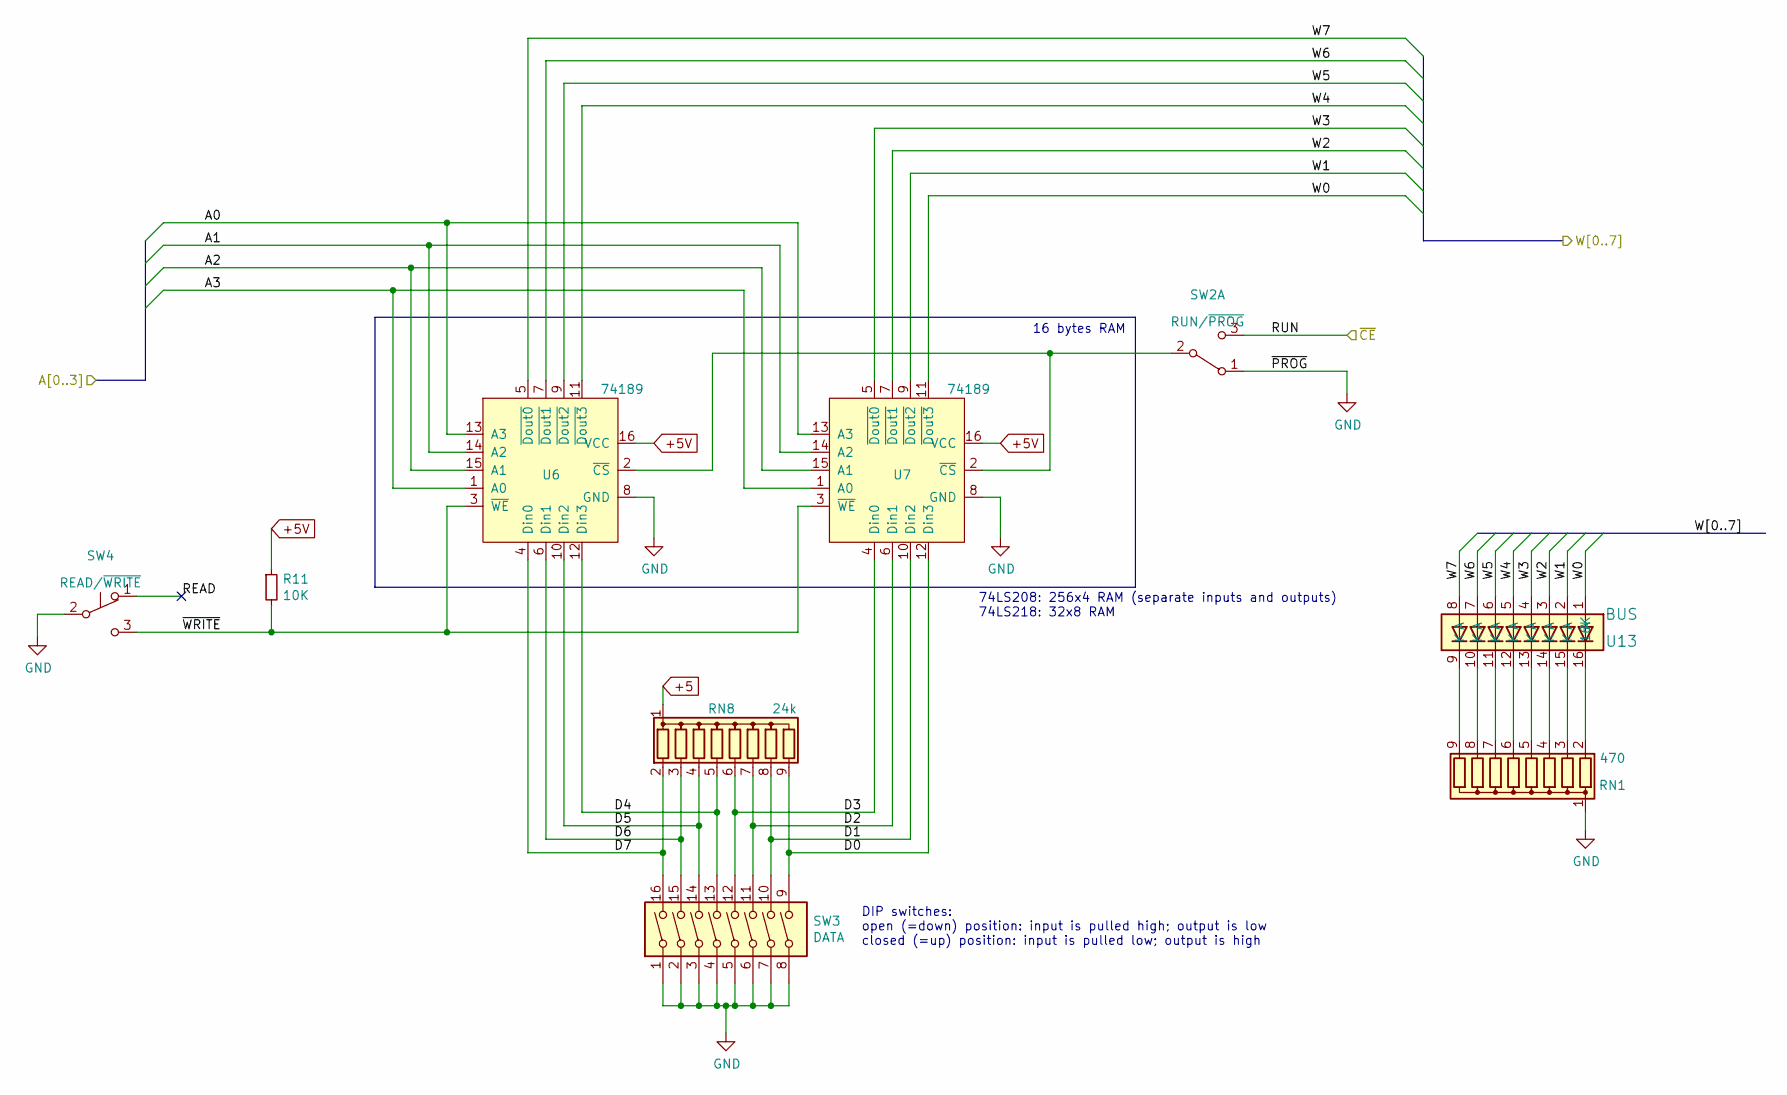
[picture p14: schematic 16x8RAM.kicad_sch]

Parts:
R11: 10K; R_Axial_DIN0207_L6.3mm_D2.5mm_P7.62mm_Horizontal
RN1: 470; R_Array_SIP9
RN8: 24k; R_Array_SIP9
SW2: RUN/~{PROG}; SW_CuK_JS202011AQN_DPDT_Angled
SW3: DATA; SW_DIP_SPSTx08_Slide_6.7x21.88mm_W7.62mm_P2.54mm_LowProfile
SW4: READ/~{WRITE}; SW_Push_1P2T_Vertical_E-Switch_800UDP8P1A1M6
U6, U7: 74189; DIP-16_W7.62mm_LongPads
U13: BUS; DIP-16_W7.62mm_LongPads

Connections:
+5: RN8.1 (common); also elsewhere on the board
+5V: R11.1, U6.16 (VCC), U7.16 (VCC); also elsewhere on the board
/3-InputAndMAR/A0: U6.13 (A3), U7.13 (A3); also elsewhere on the board
/3-InputAndMAR/A1: U6.14 (A2), U7.14 (A2); also elsewhere on the board
/3-InputAndMAR/A2: U6.15 (A1), U7.15 (A1); also elsewhere on the board
/3-InputAndMAR/A3: U6.1 (A0), U7.1 (A0); also elsewhere on the board
/4-16x8RAM/D0: RN8.9 (R8), SW3.9, U7.12 (Din3)
/4-16x8RAM/D1: RN8.8 (R7), SW3.10, U7.10 (Din2)
/4-16x8RAM/D2: RN8.7 (R6), SW3.11, U7.6 (Din1)
/4-16x8RAM/D3: RN8.6 (R5), SW3.12, U7.4 (Din0)
/4-16x8RAM/D4: RN8.5 (R4), SW3.13, U6.12 (Din3)
/4-16x8RAM/D5: RN8.4 (R3), SW3.14, U6.10 (Din2)
/4-16x8RAM/D6: RN8.3 (R2), SW3.15, U6.6 (Din1)
/4-16x8RAM/D7: RN8.2 (R1), SW3.16, U6.4 (Din0)
/4-16x8RAM/READ: SW4.1 (A)
/4-16x8RAM/RUN: SW2.3 (C); also elsewhere on the board
/4-16x8RAM/W0: U7.11 (~Dout3), U13.1 (A); also elsewhere on the board
/4-16x8RAM/W1: U7.9 (~Dout2), U13.2 (A); also elsewhere on the board
/4-16x8RAM/W2: U7.7 (~Dout1), U13.3 (A); also elsewhere on the board
/4-16x8RAM/W3: U7.5 (~Dout0), U13.4 (A); also elsewhere on the board
/4-16x8RAM/W4: U6.11 (~Dout3), U13.5 (A); also elsewhere on the board
/4-16x8RAM/W5: U6.9 (~Dout2), U13.6 (A); also elsewhere on the board
/4-16x8RAM/W6: U6.7 (~Dout1), U13.7 (A); also elsewhere on the board
/4-16x8RAM/W7: U6.5 (~Dout0), U13.8 (A); also elsewhere on the board
/4-16x8RAM/~WRITE: R11.2, SW4.3 (C), U6.3 (~WE), U7.3 (~WE)
GND: RN1.1 (common), SW2.1 (A), SW3.1, SW3.2, SW3.3, SW3.4, SW3.5, SW3.6, SW3.7, SW3.8, SW4.2 (B), U6.8 (GND), U7.8 (GND); also elsewhere on the board
unnamed: RN1.2 (R1), U13.16 (16K)
unnamed: RN1.3 (R2), U13.15 (K)
unnamed: RN1.4 (R3), U13.14 (K)
unnamed: RN1.5 (R4), U13.13 (K)
unnamed: RN1.6 (R5), U13.12 (K)
unnamed: RN1.7 (R6), U13.11 (K)
unnamed: RN1.8 (R7), U13.10 (K)
unnamed: RN1.9 (R8), U13.9 (K)
unnamed: SW2.2 (B), U6.2 (~CS), U7.2 (~CS)

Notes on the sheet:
DIP switches: open (=down) position: input is pulled high; output is low closed (=up) position: input is pulled low; output is high
16 bytes RAM
74LS208: 256x4 RAM (separate inputs and outputs) 74LS218: 32x8 RAM

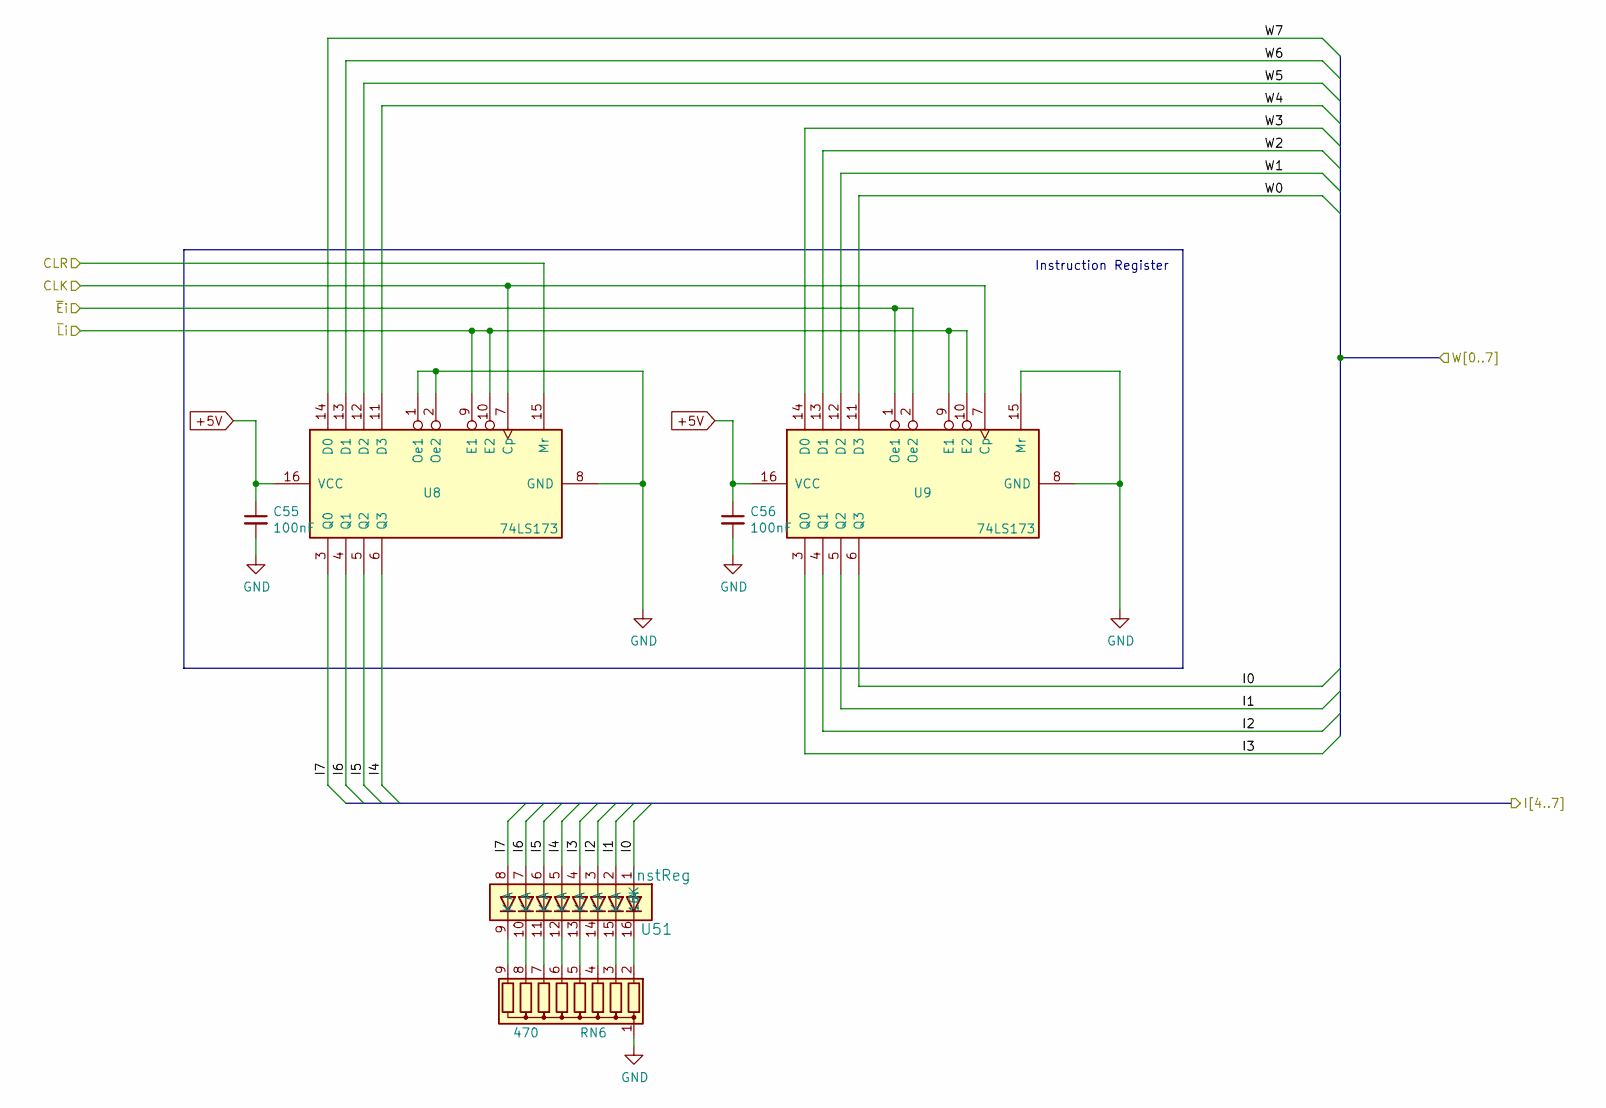
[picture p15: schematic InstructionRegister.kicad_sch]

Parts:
C55, C56: 100nF; C_0805_2012Metric
RN6: 470; R_Array_SIP9
U8, U9: 74LS173; DIP-16_W7.62mm_LongPads
U51: InstReg; DIP-16_W7.62mm_LongPads

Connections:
+5V: C55.1, C56.1, U8.16 (VCC), U9.16 (VCC); also elsewhere on the board
/1-PowerClock/CLK: U8.7 (Cp), U9.7 (Cp); also elsewhere on the board
/1-PowerClock/CLR: U8.15 (Mr); also elsewhere on the board
/4-16x8RAM/W0: U9.11 (D3); also elsewhere on the board
/4-16x8RAM/W1: U9.12 (D2); also elsewhere on the board
/4-16x8RAM/W2: U9.13 (D1); also elsewhere on the board
/4-16x8RAM/W3: U9.14 (D0); also elsewhere on the board
/4-16x8RAM/W4: U8.11 (D3); also elsewhere on the board
/4-16x8RAM/W5: U8.12 (D2); also elsewhere on the board
/4-16x8RAM/W6: U8.13 (D1); also elsewhere on the board
/4-16x8RAM/W7: U8.14 (D0); also elsewhere on the board
/5-InstructionRegister/I0: U9.6 (Q3), U51.1 (A)
/5-InstructionRegister/I1: U9.5 (Q2), U51.2 (A)
/5-InstructionRegister/I2: U9.4 (Q1), U51.3 (A)
/5-InstructionRegister/I3: U9.3 (Q0), U51.4 (A)
/5-InstructionRegister/I4: U8.6 (Q3), U51.5 (A); also elsewhere on the board
/5-InstructionRegister/I5: U8.5 (Q2), U51.6 (A); also elsewhere on the board
/5-InstructionRegister/I6: U8.4 (Q1), U51.7 (A); also elsewhere on the board
/5-InstructionRegister/I7: U8.3 (Q0), U51.8 (A); also elsewhere on the board
/5-InstructionRegister/~Ei: U9.1 (Oe1), U9.2 (Oe2); also elsewhere on the board
/5-InstructionRegister/~Li: U8.9 (E1), U8.10 (E2), U9.9 (E1), U9.10 (E2); also elsewhere on the board
GND: C55.2, C56.2, RN6.1 (common), U8.1 (Oe1), U8.2 (Oe2), U8.8 (GND), U9.8 (GND), U9.15 (Mr); also elsewhere on the board
unnamed: RN6.2 (R1), U51.16 (16K)
unnamed: RN6.3 (R2), U51.15 (K)
unnamed: RN6.4 (R3), U51.14 (K)
unnamed: RN6.5 (R4), U51.13 (K)
unnamed: RN6.6 (R5), U51.12 (K)
unnamed: RN6.7 (R6), U51.11 (K)
unnamed: RN6.8 (R7), U51.10 (K)
unnamed: RN6.9 (R8), U51.9 (K)

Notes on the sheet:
Instruction Register

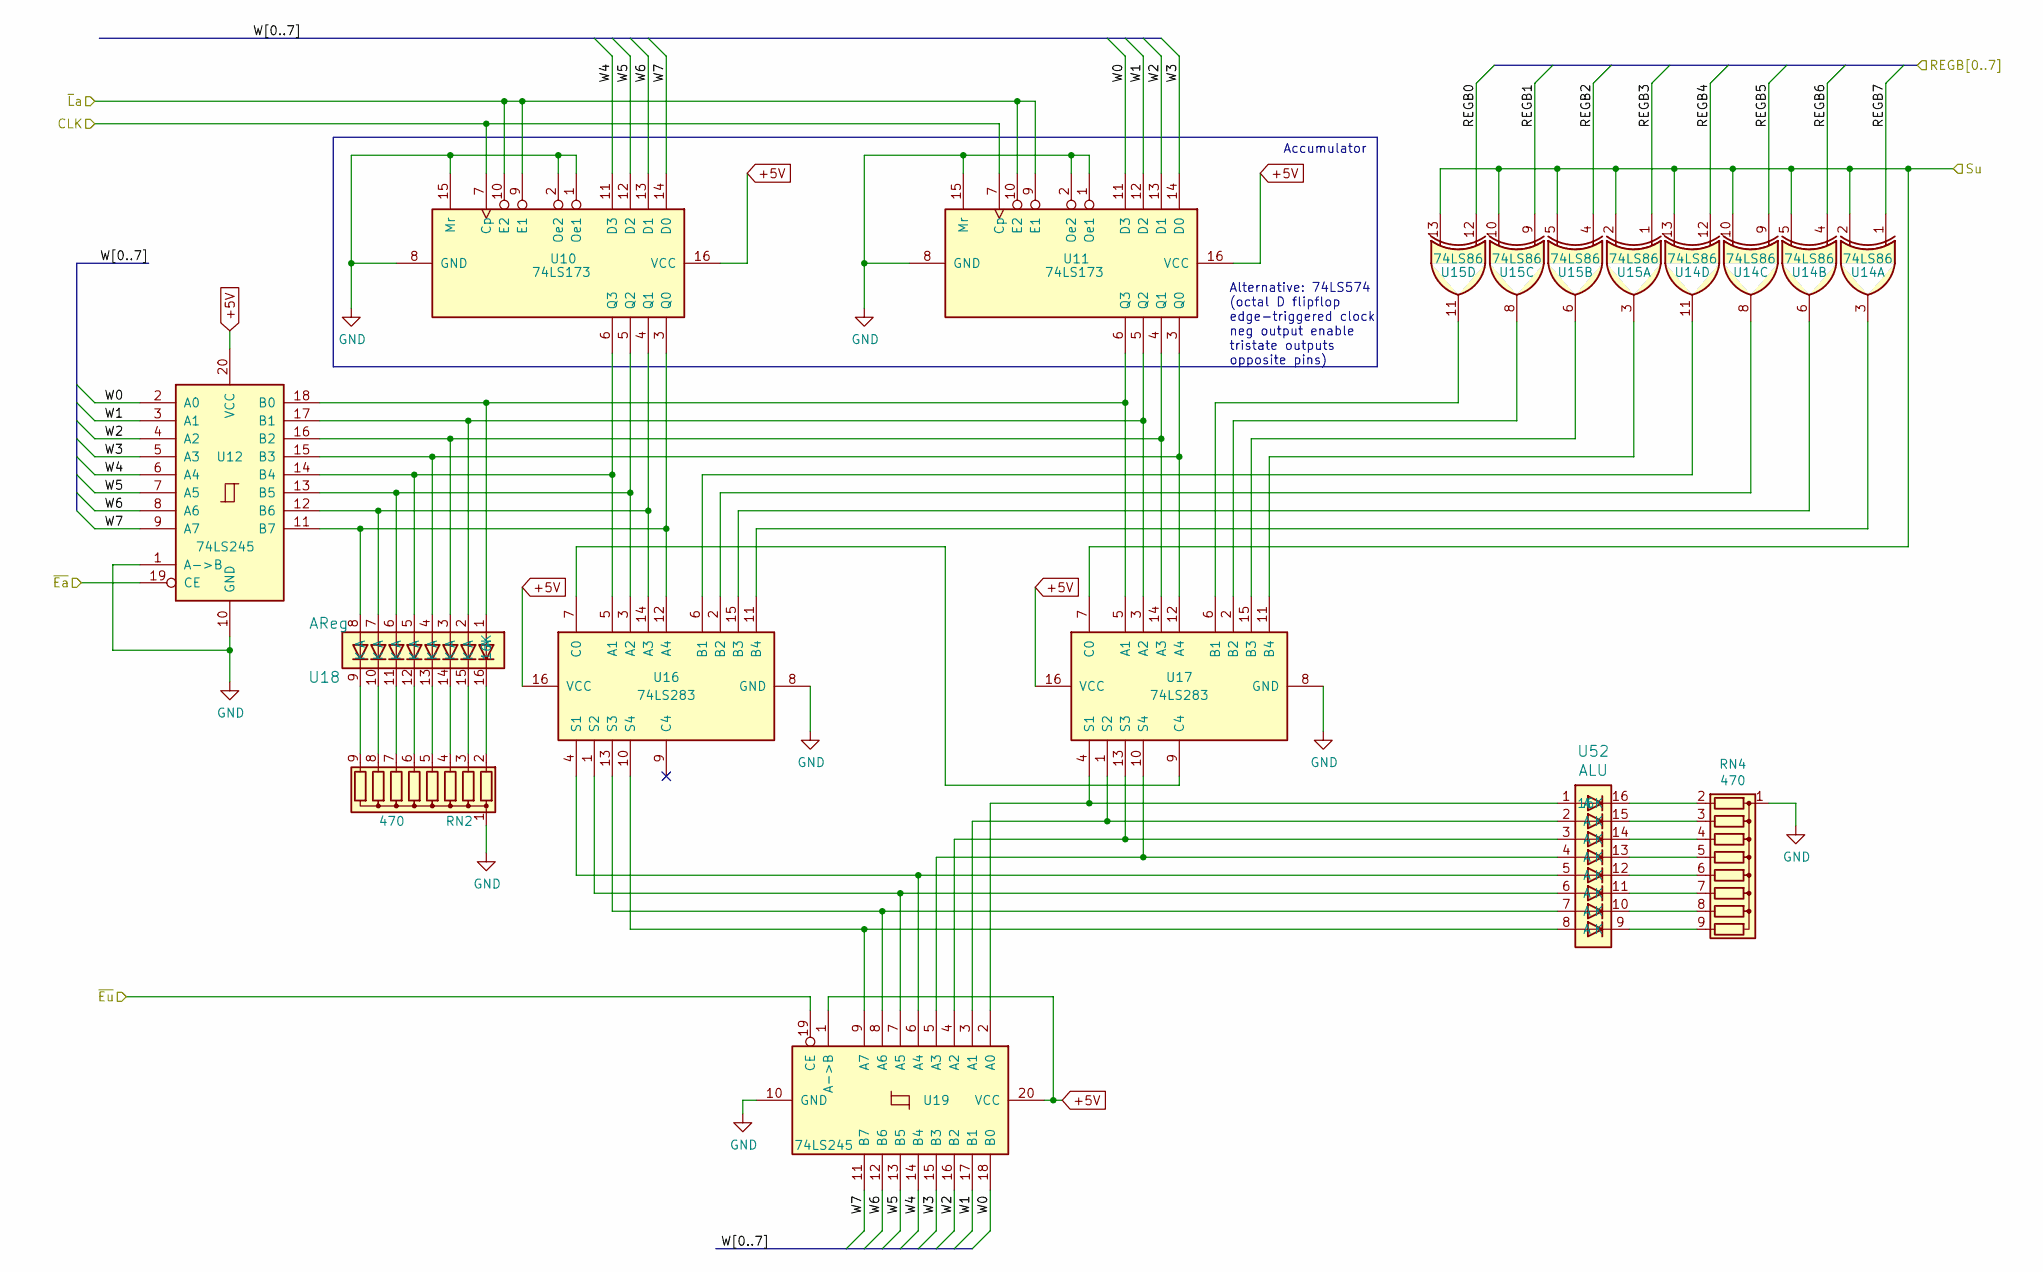
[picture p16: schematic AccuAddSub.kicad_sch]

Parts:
RN2, RN4: 470; R_Array_SIP9
U10, U11: 74LS173; DIP-16_W7.62mm_LongPads
U12, U19: 74LS245; DIP-20_W7.62mm_LongPads
U14, U15: 74LS86; DIP-14_W7.62mm_LongPads
U16, U17: 74LS283; DIP-16_W7.62mm_LongPads
U18: AReg; DIP-16_W7.62mm_LongPads
U52: ALU; DIP-16_W7.62mm_LongPads

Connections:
+5V: U10.16 (VCC), U11.16 (VCC), U12.20 (VCC), U16.16 (VCC), U17.16 (VCC), U19.1 (A->B), U19.20 (VCC); also elsewhere on the board
/1-PowerClock/CLK: U10.7 (Cp), U11.7 (Cp); also elsewhere on the board
/6-AccuAddSub/REGB0: U15.12; also elsewhere on the board
/6-AccuAddSub/REGB1: U15.9; also elsewhere on the board
/6-AccuAddSub/REGB2: U15.4; also elsewhere on the board
/6-AccuAddSub/REGB3: U15.1; also elsewhere on the board
/6-AccuAddSub/REGB4: U14.12; also elsewhere on the board
/6-AccuAddSub/REGB5: U14.9; also elsewhere on the board
/6-AccuAddSub/REGB6: U14.4; also elsewhere on the board
/6-AccuAddSub/REGB7: U14.1; also elsewhere on the board
/6-AccuAddSub/Su: U14.2, U14.5, U14.10, U14.13, U15.2, U15.5, U15.10, U15.13, U17.7 (C0); also elsewhere on the board
/6-AccuAddSub/W0: U11.11 (D3), U12.2 (A0), U19.18 (B0)
/6-AccuAddSub/W1: U11.12 (D2), U12.3 (A1), U19.17 (B1)
/6-AccuAddSub/W2: U11.13 (D1), U12.4 (A2), U19.16 (B2)
/6-AccuAddSub/W3: U11.14 (D0), U12.5 (A3), U19.15 (B3)
/6-AccuAddSub/W4: U10.11 (D3), U12.6 (A4), U19.14 (B4)
/6-AccuAddSub/W5: U10.12 (D2), U12.7 (A5), U19.13 (B5)
/6-AccuAddSub/W6: U10.13 (D1), U12.8 (A6), U19.12 (B6)
/6-AccuAddSub/W7: U10.14 (D0), U12.9 (A7), U19.11 (B7)
/6-AccuAddSub/~Ea: U12.19 (CE); also elsewhere on the board
/6-AccuAddSub/~Eu: U19.19 (CE); also elsewhere on the board
/6-AccuAddSub/~La: U10.9 (E1), U10.10 (E2), U11.9 (E1), U11.10 (E2); also elsewhere on the board
GND: RN2.1 (common), RN4.1 (common), U10.1 (Oe1), U10.2 (Oe2), U10.8 (GND), U10.15 (Mr), U11.1 (Oe1), U11.2 (Oe2), U11.8 (GND), U11.15 (Mr), U12.1 (A->B), U12.10 (GND), U16.8 (GND), U17.8 (GND), U19.10 (GND); also elsewhere on the board
unnamed: RN2.2 (R1), U18.16 (16K)
unnamed: RN2.3 (R2), U18.15 (K)
unnamed: RN2.4 (R3), U18.14 (K)
unnamed: RN2.5 (R4), U18.13 (K)
unnamed: RN2.6 (R5), U18.12 (K)
unnamed: RN2.7 (R6), U18.11 (K)
unnamed: RN2.8 (R7), U18.10 (K)
unnamed: RN2.9 (R8), U18.9 (K)
unnamed: RN4.2 (R1), U52.16 (16K)
unnamed: RN4.3 (R2), U52.15 (K)
unnamed: RN4.4 (R3), U52.14 (K)
unnamed: RN4.5 (R4), U52.13 (K)
unnamed: RN4.6 (R5), U52.12 (K)
unnamed: RN4.7 (R6), U52.11 (K)
unnamed: RN4.8 (R7), U52.10 (K)
unnamed: RN4.9 (R8), U52.9 (K)
unnamed: U10.3 (Q0), U12.11 (B7), U16.12 (A4), U18.8 (A)
unnamed: U10.4 (Q1), U12.12 (B6), U16.14 (A3), U18.7 (A)
unnamed: U10.5 (Q2), U12.13 (B5), U16.3 (A2), U18.6 (A)
unnamed: U10.6 (Q3), U12.14 (B4), U16.5 (A1), U18.5 (A)
unnamed: U11.3 (Q0), U12.15 (B3), U17.12 (A4), U18.4 (A)
unnamed: U11.4 (Q1), U12.16 (B2), U17.14 (A3), U18.3 (A)
unnamed: U11.5 (Q2), U12.17 (B1), U17.3 (A2), U18.2 (A)
unnamed: U11.6 (Q3), U12.18 (B0), U17.5 (A1), U18.1 (A)
unnamed: U14.3, U16.11 (B4)
unnamed: U14.6, U16.15 (B3)
unnamed: U14.8, U16.2 (B2)
unnamed: U14.11, U16.6 (B1)
unnamed: U15.3, U17.11 (B4)
unnamed: U15.6, U17.15 (B3)
unnamed: U15.8, U17.2 (B2)
unnamed: U15.11, U17.6 (B1)
unnamed: U16.1 (S2), U19.7 (A5), U52.6 (A)
unnamed: U16.4 (S1), U19.6 (A4), U52.5 (A)
unnamed: U16.7 (C0), U17.9 (C4)
unnamed: U16.10 (S4), U19.9 (A7), U52.8 (A)
unnamed: U16.13 (S3), U19.8 (A6), U52.7 (A)
unnamed: U17.1 (S2), U19.3 (A1), U52.2 (A)
unnamed: U17.4 (S1), U19.2 (A0), U52.1 (A)
unnamed: U17.10 (S4), U19.5 (A3), U52.4 (A)
unnamed: U17.13 (S3), U19.4 (A2), U52.3 (A)

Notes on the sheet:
Accumulator
Alternative: 74LS574 (octal D flipflop edge-triggered clock neg output enable tristate outputs opposite pins)

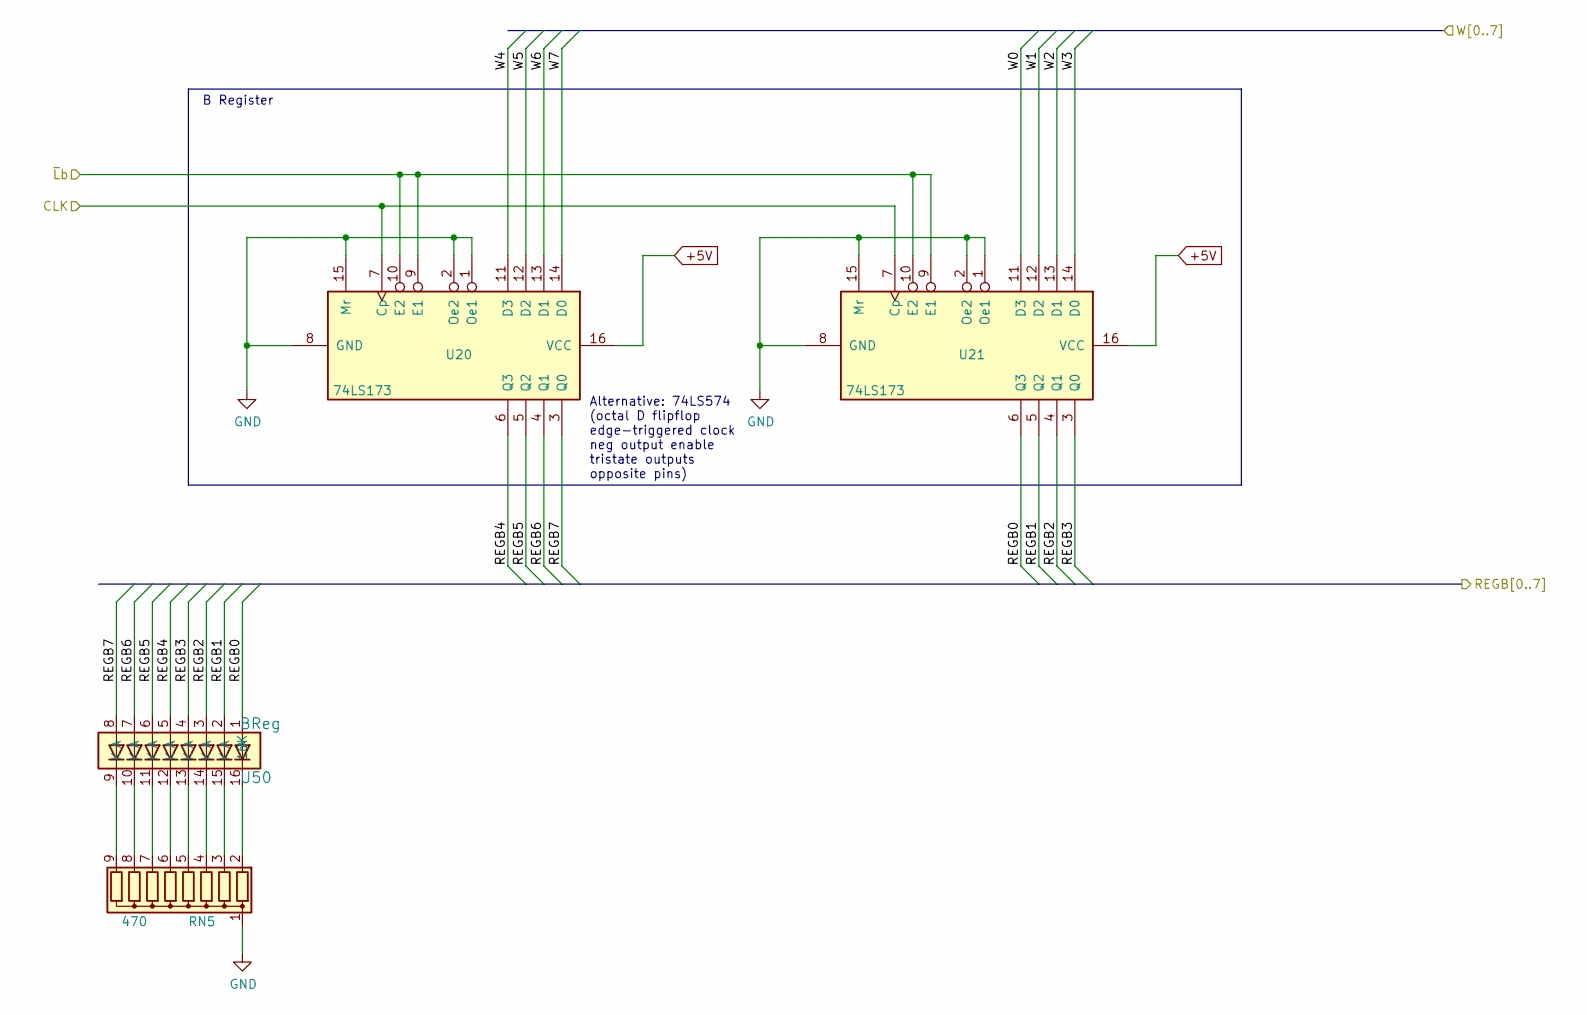
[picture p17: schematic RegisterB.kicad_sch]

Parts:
RN5: 470; R_Array_SIP9
U20, U21: 74LS173; DIP-16_W7.62mm_LongPads
U50: BReg; DIP-16_W7.62mm_LongPads

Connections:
+5V: U20.16 (VCC), U21.16 (VCC); also elsewhere on the board
/1-PowerClock/CLK: U20.7 (Cp), U21.7 (Cp); also elsewhere on the board
/4-16x8RAM/W0: U21.11 (D3); also elsewhere on the board
/4-16x8RAM/W1: U21.12 (D2); also elsewhere on the board
/4-16x8RAM/W2: U21.13 (D1); also elsewhere on the board
/4-16x8RAM/W3: U21.14 (D0); also elsewhere on the board
/4-16x8RAM/W4: U20.11 (D3); also elsewhere on the board
/4-16x8RAM/W5: U20.12 (D2); also elsewhere on the board
/4-16x8RAM/W6: U20.13 (D1); also elsewhere on the board
/4-16x8RAM/W7: U20.14 (D0); also elsewhere on the board
/6-AccuAddSub/REGB0: U21.6 (Q3), U50.1 (A); also elsewhere on the board
/6-AccuAddSub/REGB1: U21.5 (Q2), U50.2 (A); also elsewhere on the board
/6-AccuAddSub/REGB2: U21.4 (Q1), U50.3 (A); also elsewhere on the board
/6-AccuAddSub/REGB3: U21.3 (Q0), U50.4 (A); also elsewhere on the board
/6-AccuAddSub/REGB4: U20.6 (Q3), U50.5 (A); also elsewhere on the board
/6-AccuAddSub/REGB5: U20.5 (Q2), U50.6 (A); also elsewhere on the board
/6-AccuAddSub/REGB6: U20.4 (Q1), U50.7 (A); also elsewhere on the board
/6-AccuAddSub/REGB7: U20.3 (Q0), U50.8 (A); also elsewhere on the board
/7-RegisterB/~Lb: U20.9 (E1), U20.10 (E2), U21.9 (E1), U21.10 (E2); also elsewhere on the board
GND: RN5.1 (common), U20.1 (Oe1), U20.2 (Oe2), U20.8 (GND), U20.15 (Mr), U21.1 (Oe1), U21.2 (Oe2), U21.8 (GND), U21.15 (Mr); also elsewhere on the board
unnamed: RN5.2 (R1), U50.16 (16K)
unnamed: RN5.3 (R2), U50.15 (K)
unnamed: RN5.4 (R3), U50.14 (K)
unnamed: RN5.5 (R4), U50.13 (K)
unnamed: RN5.6 (R5), U50.12 (K)
unnamed: RN5.7 (R6), U50.11 (K)
unnamed: RN5.8 (R7), U50.10 (K)
unnamed: RN5.9 (R8), U50.9 (K)

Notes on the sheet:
Alternative: 74LS574 (octal D flipflop edge-triggered clock neg output enable tristate outputs opposite pins)
B Register

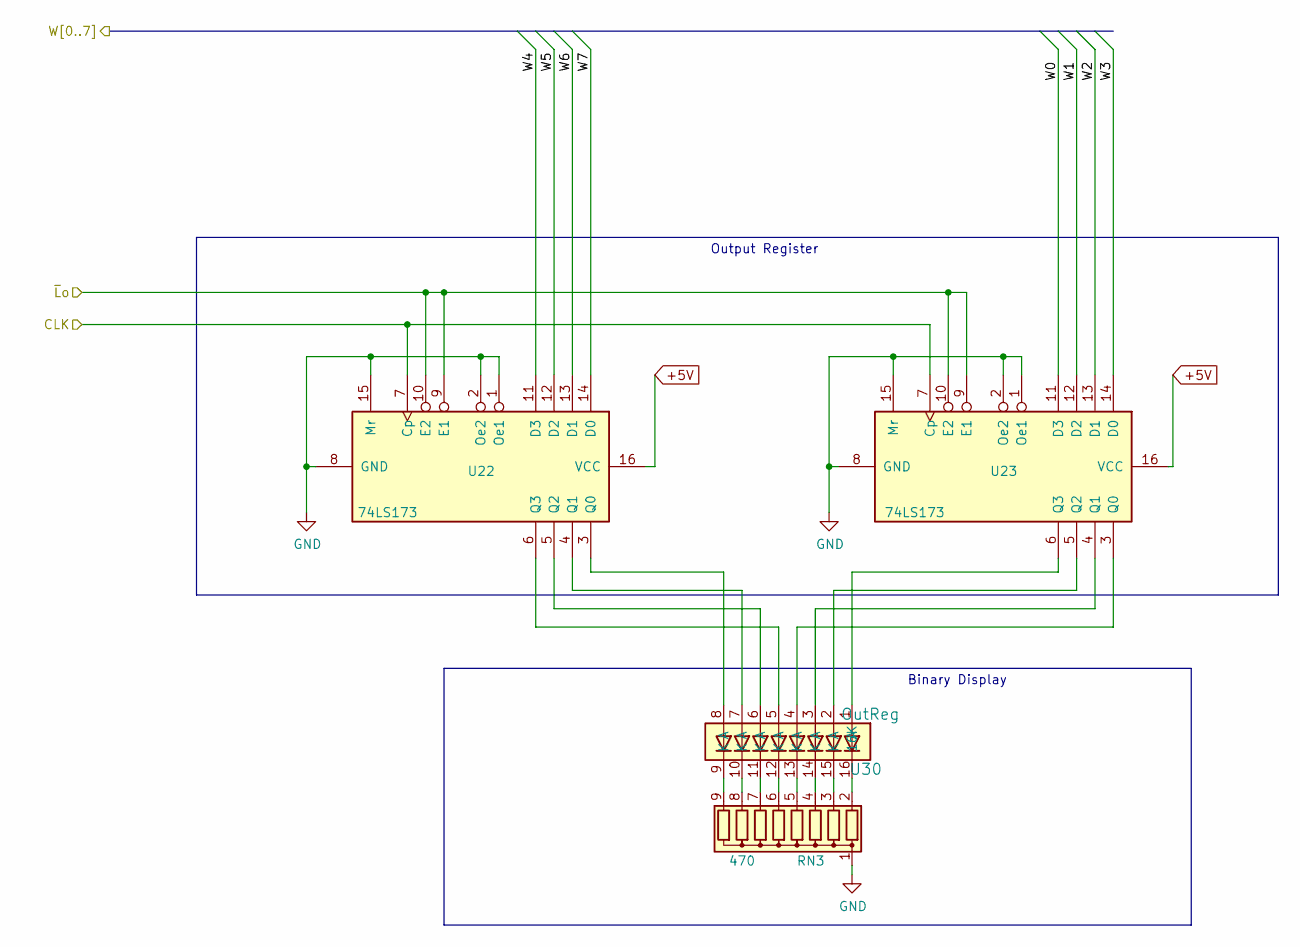
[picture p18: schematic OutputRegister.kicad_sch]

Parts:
RN3: 470; R_Array_SIP9
U22, U23: 74LS173; DIP-16_W7.62mm_LongPads
U30: OutReg; DIP-16_W7.62mm_LongPads

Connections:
+5V: U22.16 (VCC), U23.16 (VCC); also elsewhere on the board
/1-PowerClock/CLK: U22.7 (Cp), U23.7 (Cp); also elsewhere on the board
/4-16x8RAM/W0: U23.11 (D3); also elsewhere on the board
/4-16x8RAM/W1: U23.12 (D2); also elsewhere on the board
/4-16x8RAM/W2: U23.13 (D1); also elsewhere on the board
/4-16x8RAM/W3: U23.14 (D0); also elsewhere on the board
/4-16x8RAM/W4: U22.11 (D3); also elsewhere on the board
/4-16x8RAM/W5: U22.12 (D2); also elsewhere on the board
/4-16x8RAM/W6: U22.13 (D1); also elsewhere on the board
/4-16x8RAM/W7: U22.14 (D0); also elsewhere on the board
/8-OutputRegister/~Lo: U22.9 (E1), U22.10 (E2), U23.9 (E1), U23.10 (E2); also elsewhere on the board
GND: RN3.1 (common), U22.1 (Oe1), U22.2 (Oe2), U22.8 (GND), U22.15 (Mr), U23.1 (Oe1), U23.2 (Oe2), U23.8 (GND), U23.15 (Mr); also elsewhere on the board
unnamed: RN3.2 (R1), U30.16 (16K)
unnamed: RN3.3 (R2), U30.15 (K)
unnamed: RN3.4 (R3), U30.14 (K)
unnamed: RN3.5 (R4), U30.13 (K)
unnamed: RN3.6 (R5), U30.12 (K)
unnamed: RN3.7 (R6), U30.11 (K)
unnamed: RN3.8 (R7), U30.10 (K)
unnamed: RN3.9 (R8), U30.9 (K)
unnamed: U22.3 (Q0), U30.8 (A)
unnamed: U22.4 (Q1), U30.7 (A)
unnamed: U22.5 (Q2), U30.6 (A)
unnamed: U22.6 (Q3), U30.5 (A)
unnamed: U23.3 (Q0), U30.4 (A)
unnamed: U23.4 (Q1), U30.3 (A)
unnamed: U23.5 (Q2), U30.2 (A)
unnamed: U23.6 (Q3), U30.1 (A)

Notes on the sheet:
Binary Display
Output Register

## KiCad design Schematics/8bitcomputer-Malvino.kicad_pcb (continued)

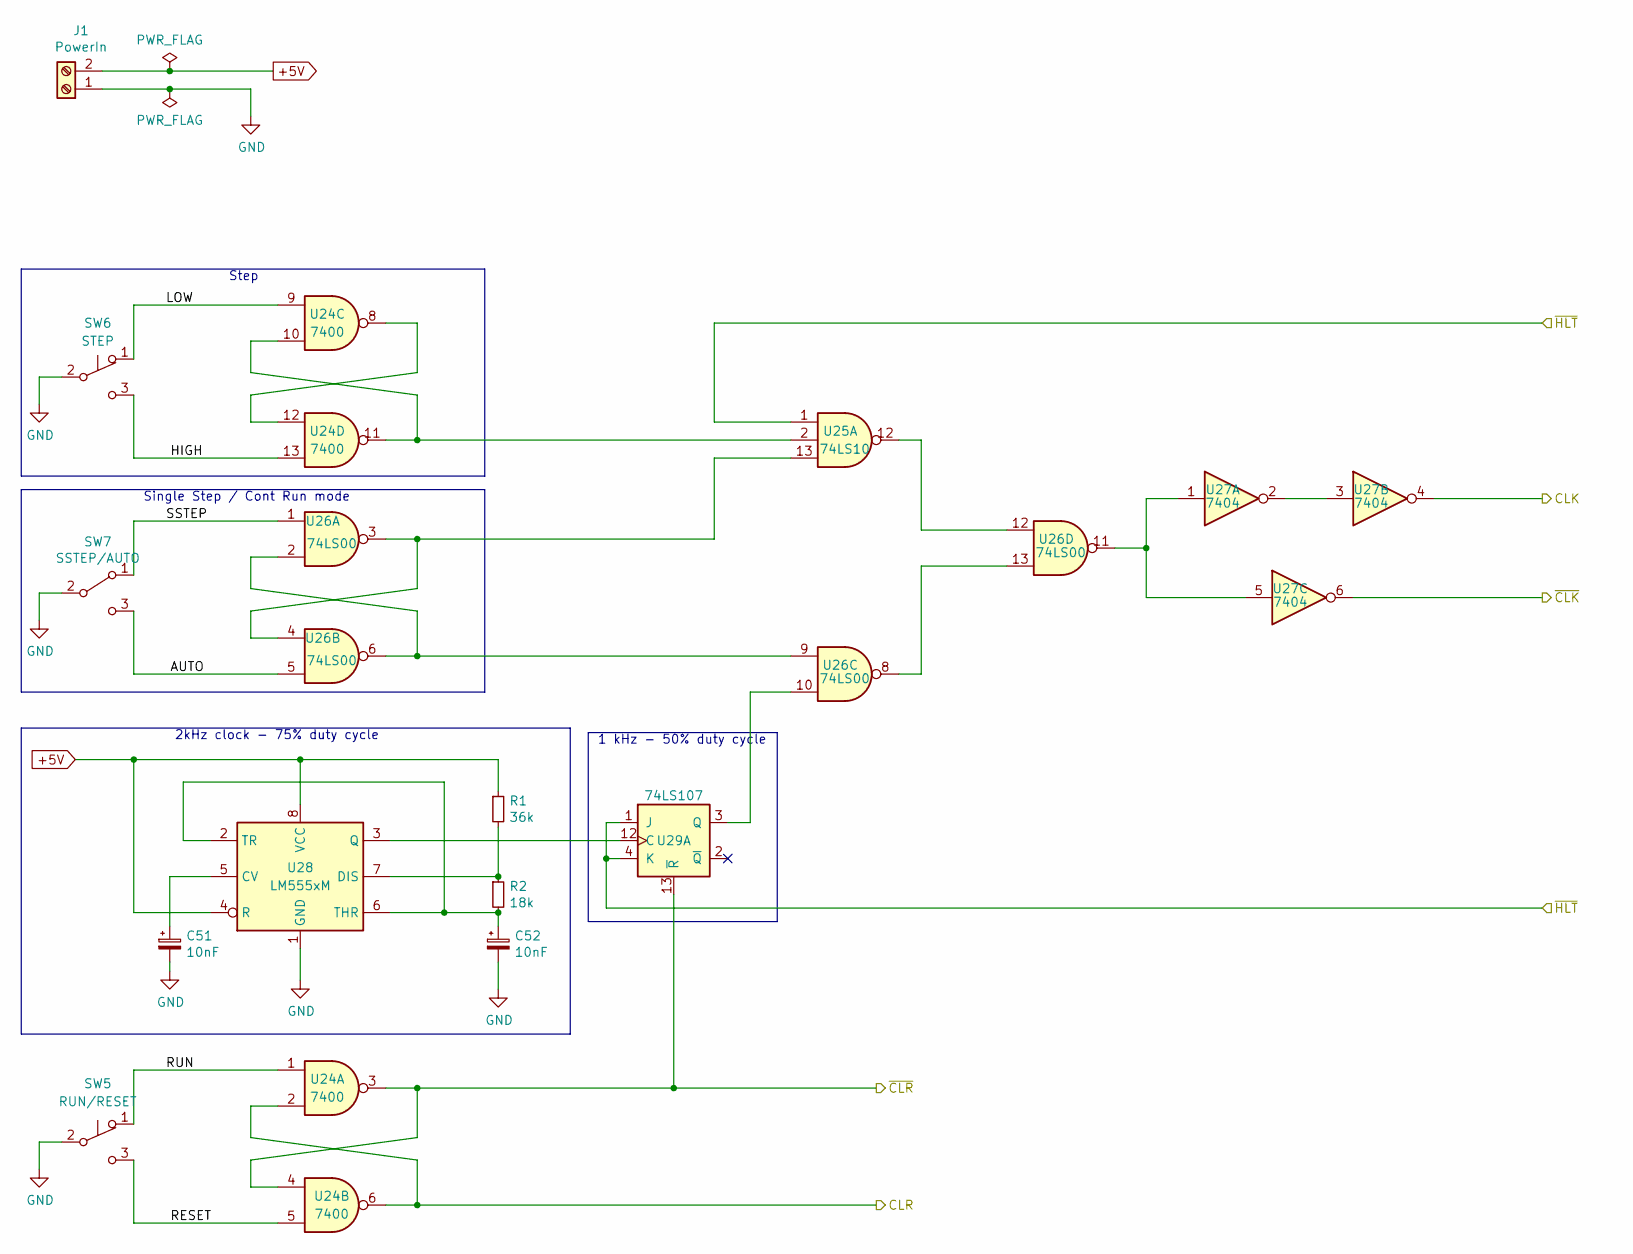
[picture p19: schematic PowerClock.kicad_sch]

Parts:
C51, C52: 10nF; C_Disc_D7.5mm_W5.0mm_P7.50mm
J1: PowerIn; TerminalBlock_Phoenix_MKDS-1,5-2-5.08_1x02_P5.08mm_Horizont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
R1: 36k; R_Axial_DIN0207_L6.3mm_D2.5mm_P7.62mm_Horizontal
R2: 18k; R_Axial_DIN0207_L6.3mm_D2.5mm_P7.62mm_Horizontal
SW5: RUN/RESET; SW_Push_1P2T_Vertical_E-Switch_800UDP8P1A1M6
SW6: STEP; SW_CuK_OS102011MA1QN1_SPDT_Angled
SW7: SSTEP/AUTO; TerminalBlock_Phoenix_MKDS-1,5-3-5.08_1x03_P5.08mm_Horizont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
U24: 7400; DIP-14_W7.62mm_LongPads
U25: 74LS10; DIP-14_W7.62mm_LongPads
U26: 74LS00; DIP-14_W7.62mm_LongPads
U27: 7404; DIP-14_W7.62mm_LongPads
U28: LM555xM; DIP-8_W7.62mm_LongPads
U29: 74LS107; DIP-14_W7.62mm_LongPads

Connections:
+5V: J1.2, R1.1, U28.4 (R), U28.8 (VCC); also elsewhere on the board
/1-PowerClock/AUTO: SW7.3 (C), U26.5
/1-PowerClock/CLK: U27.4; also elsewhere on the board
/1-PowerClock/CLR: U24.2, U24.6; also elsewhere on the board
/1-PowerClock/HIGH: SW6.3 (C), U24.13
/1-PowerClock/LOW: SW6.1 (A), U24.9
/1-PowerClock/RESET: SW5.3 (C), U24.5
/1-PowerClock/RUN: SW5.1 (A), U24.1
/1-PowerClock/SSTEP: SW7.1 (A), U26.1
/1-PowerClock/~CLK: U27.6
/1-PowerClock/~CLR: U24.3, U24.4, U29.13 (~R); also elsewhere on the board
/1-PowerClock/~HLT: U25.1, U29.1 (J), U29.4 (K); also elsewhere on the board
GND: C51.2, C52.2, J1.1, SW5.2 (B), SW6.2 (B), SW7.2 (B), U28.1 (GND); also elsewhere on the board
unnamed: C51.1, U28.5 (CV)
unnamed: C52.1, R2.2, U28.2 (TR), U28.6 (THR)
unnamed: R1.2, R2.1, U28.7 (DIS)
unnamed: U24.10, U24.11, U25.2
unnamed: U24.8, U24.12
unnamed: U25.12, U26.12
unnamed: U25.13, U26.3, U26.4
unnamed: U26.2, U26.6, U26.9
unnamed: U26.10, U29.3 (Q)
unnamed: U26.11, U27.1, U27.5
unnamed: U26.8, U26.13
unnamed: U27.2, U27.3
unnamed: U28.3 (Q), U29.12 (C)

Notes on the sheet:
Step
2kHz clock - 75% duty cycle
1 kHz - 50% duty cycle
Single Step / Cont Run mode

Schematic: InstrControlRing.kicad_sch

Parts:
D1, D2, D3, D4, D5, D6: Grn; LED_D3.0mm
D7: Cp; LED_D3.0mm
D8: Ep; LED_D3.0mm
D9: Lm; LED_D3.0mm
D14: CE; LED_D3.0mm
D15: Li; LED_D3.0mm
D16: Ei; LED_D3.0mm
D17: La; LED_D3.0mm
D18: Ea; LED_D3.0mm
D19: Su; LED_D3.0mm
D20: Eu; LED_D3.0mm
D21: Lb; LED_D3.0mm
D22: L0; LED_D3.0mm
D23: HLT; LED_D3.0mm
D24: OUT; LED_D3.0mm
D25: SUB; LED_D3.0mm
D26: ADD; LED_D3.0mm
D27: LDA; LED_D3.0mm
R3, R4, R5, R6, R7, R8, R9, R10, R16, R17, R18, R19, R20, R21, R22, R23, R24, R25, R26, R27, R28, R29, R30: 620; R_0805_2012Metric
U31, U35, U47, U48, U49: 74LS04; DIP-14_W7.62mm_LongPads
U32, U33, U34, U44: 74LS20; DIP-14_W7.62mm_LongPads
U36, U37, U38: 74LS107; DIP-14_W7.62mm_LongPads
U39, U40, U41, U42, U43, U46: 74LS00; DIP-14_W7.62mm_LongPads
U45: 74LS10; DIP-14_W7.62mm_LongPads

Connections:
/1-PowerClock/CLK: U36.9 (C), U36.12 (C), U37.9 (C), U37.12 (C), U38.9 (C), U38.12 (C); also elsewhere on the board
/1-PowerClock/~CLR: U36.10 (~R), U36.13 (~R), U37.10 (~R), U37.13 (~R), U38.10 (~R), U38.13 (~R); also elsewhere on the board
/1-PowerClock/~HLT: D23.2 (A), U34.6; also elsewhere on the board
/2-ProgramCounter/~Ep: U47.2; also elsewhere on the board
/3-InputAndMAR/~Lm: D9.2 (A), U48.6; also elsewhere on the board
/4-16x8RAM/RUN: D14.2 (A), U47.4; also elsewhere on the board
/5-InstructionRegister/I4: U31.9, U32.13, U34.5; also elsewhere on the board
/5-InstructionRegister/I5: U31.5, U33.4, U33.12, U34.4; also elsewhere on the board
/5-InstructionRegister/I6: U31.3, U33.10, U34.2; also elsewhere on the board
/5-InstructionRegister/I7: U31.1, U33.9, U34.1; also elsewhere on the board
/5-InstructionRegister/~Ei: D16.2 (A), U47.8; also elsewhere on the board
/5-InstructionRegister/~Li: D15.2 (A), U47.6; also elsewhere on the board
/6-AccuAddSub/Su: D19.2 (A), U48.2; also elsewhere on the board
/6-AccuAddSub/~Ea: U49.2; also elsewhere on the board
/6-AccuAddSub/~Eu: U49.4; also elsewhere on the board
/6-AccuAddSub/~La: D17.2 (A), U47.10; also elsewhere on the board
/7-RegisterB/~Lb: D21.2 (A), U48.4; also elsewhere on the board
/8-OutputRegister/~Lo: D22.2 (A), U43.8, U48.9; also elsewhere on the board
/9-InstrControlRing/ADD: D26.2 (A), U35.4, U39.4, U40.1, U40.12, U41.9, U42.9, U43.1
/9-InstrControlRing/Ea: D18.2 (A), U47.12, U49.1
/9-InstrControlRing/Eu: D20.2 (A), U46.3, U49.3
/9-InstrControlRing/LDA: D27.2 (A), U35.2, U39.1, U39.12, U40.9, U41.4
/9-InstrControlRing/Lo: U48.8
/9-InstrControlRing/OUT: D24.2 (A), U35.8, U42.1, U43.9
/9-InstrControlRing/SUB: D25.2 (A), U35.6, U39.9, U40.4, U41.1, U41.12, U42.4, U42.12, U43.4
/9-InstrControlRing/T1: D1.2 (A), D8.2 (A), U35.11, U38.1 (J), U38.6 (~Q), U47.1
/9-InstrControlRing/T2: D2.2 (A), D7.2 (A), U37.8 (J), U38.3 (Q); also elsewhere on the board
/9-InstrControlRing/T3: D3.2 (A), U35.13, U37.1 (J), U37.5 (Q), U47.5
/9-InstrControlRing/T4: D4.2 (A), U36.8 (J), U37.3 (Q), U39.2, U39.5, U39.10, U40.10, U40.13, U41.2, U42.2, U43.10
/9-InstrControlRing/T5: D5.2 (A), U36.1 (J), U36.5 (Q), U39.13, U40.2, U40.5, U41.5, U43.2, U43.5
/9-InstrControlRing/T6: D6.2 (A), U36.3 (Q), U38.11 (K), U41.10, U41.13, U42.5, U42.10, U42.13
GND: R3.2, R4.2, R5.2, R6.2, R7.2, R8.2, R9.2, R10.2, R16.2, R17.2, R18.2, R19.2, R20.2, R21.2, R22.2, R23.2, R24.2, R25.2, R26.2, R27.2, R28.2, R29.2, R30.2; also elsewhere on the board
unnamed: D1.1 (K), R3.1
unnamed: D2.1 (K), R4.1
unnamed: D3.1 (K), R5.1
unnamed: D4.1 (K), R6.1
unnamed: D5.1 (K), R7.1
unnamed: D6.1 (K), R8.1
unnamed: D7.1 (K), R9.1
unnamed: D8.1 (K), R10.1
unnamed: D9.1 (K), R16.1
unnamed: D14.1 (K), R17.1
unnamed: D15.1 (K), R18.1
unnamed: D16.1 (K), R19.1
unnamed: D17.1 (K), R20.1
unnamed: D18.1 (K), R21.1
unnamed: D19.1 (K), R22.1
unnamed: D20.1 (K), R23.1
unnamed: D21.1 (K), R24.1
unnamed: D22.1 (K), R25.1
unnamed: D23.1 (K), R26.1
unnamed: D24.1 (K), R27.1
unnamed: D25.1 (K), R28.1
unnamed: D26.1 (K), R29.1
unnamed: D27.1 (K), R30.1
unnamed: U31.2, U32.1, U32.9, U33.1
unnamed: U31.4, U32.2, U32.10, U33.2
unnamed: U31.6, U32.4, U32.12
unnamed: U31.8, U32.5, U33.5, U33.13
unnamed: U32.6, U35.1
unnamed: U32.8, U35.3
unnamed: U33.6, U35.5
unnamed: U33.8, U35.9
unnamed: U35.10, U44.1
unnamed: U35.12, U44.9
unnamed: U36.2 (~Q), U38.8 (J)
unnamed: U36.4 (K), U36.6 (~Q)
unnamed: U36.11 (K), U37.2 (~Q)
unnamed: U37.4 (K), U37.6 (~Q)
unnamed: U37.11 (K), U38.2 (~Q)
unnamed: U38.4 (K), U38.5 (Q)
unnamed: U39.3, U44.2
unnamed: U39.6, U44.4
unnamed: U39.8, U44.5
unnamed: U39.11, U44.10
unnamed: U40.3, U44.12
unnamed: U40.6, U44.13
unnamed: U40.8, U45.13
unnamed: U40.11, U45.2
unnamed: U41.3, U45.1
unnamed: U41.6, U45.5
unnamed: U41.8, U45.4
unnamed: U41.11, U45.3
unnamed: U42.3, U47.13
unnamed: U42.6, U48.1
unnamed: U42.8, U46.1
unnamed: U42.11, U46.2
unnamed: U43.3, U46.4
unnamed: U43.6, U46.5
unnamed: U44.6, U48.5
unnamed: U44.8, U47.3
unnamed: U45.6, U47.11
unnamed: U45.12, U47.9
unnamed: U46.6, U48.3

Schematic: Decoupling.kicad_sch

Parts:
C1, C2, C3, C4, C5, C6, C7, C8, C9, C10, C11, C12, C13, C14, C15, C16, C17, C18, C19, C20, C21, C22, C23, C24, C25, C26, C27, C28, C29, C31, C32, C33, C34, C35, C36, C37, C38, C39, C40, C41, C42, C43, C44, C45, C46, C47, C48: 100nF; C_0805_2012Metric
U1, U2, U29: 74LS107; DIP-14_W7.62mm_LongPads
U24: 7400; DIP-14_W7.62mm_LongPads
U25, U45: 74LS10; DIP-14_W7.62mm_LongPads
U26: 74LS00; DIP-14_W7.62mm_LongPads
U27: 7404; DIP-14_W7.62mm_LongPads
U32, U33, U34, U44: 74LS20; DIP-14_W7.62mm_LongPads

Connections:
+5: C6.1, C7.1; also elsewhere on the board
+5V: C1.1, C2.1, C3.1, C4.1, C5.1, C8.1, C9.1, C10.1, C11.1, C12.1, C13.1, C14.1, C15.1, C16.1, C17.1, C18.1, C19.1, C20.1, C21.1, C22.1, C23.1, C24.1, C25.1, C26.1, C27.1, C28.1, C29.1, C31.1, C32.1, C33.1, C34.1, C35.1, C36.1, C37.1, C38.1, C39.1, C40.1, C41.1, C42.1, C43.1, C44.1, C45.1, C46.1, C47.1, C48.1, U1.14 (VCC), U2.14 (VCC), U24.14 (VCC), U25.14 (VCC), U26.14 (VCC), U27.14 (VCC), U29.14 (VCC), U32.14 (VCC), U33.14 (VCC), U34.14 (VCC), U44.14 (VCC), U45.14 (VCC); also elsewhere on the board
GND: C1.2, C2.2, C3.2, C4.2, C5.2, C6.2, C7.2, C8.2, C9.2, C10.2, C11.2, C12.2, C13.2, C14.2, C15.2, C16.2, C17.2, C18.2, C19.2, C20.2, C21.2, C22.2, C23.2, C24.2, C25.2, C26.2, C27.2, C28.2, C29.2, C31.2, C32.2, C33.2, C34.2, C35.2, C36.2, C37.2, C38.2, C39.2, C40.2, C41.2, C42.2, C43.2, C44.2, C45.2, C46.2, C47.2, C48.2, U1.7 (GND), U2.7 (GND), U24.7 (GND), U25.7 (GND), U26.7 (GND), U27.7 (GND), U29.7 (GND), U32.7 (GND), U33.7 (GND), U34.7 (GND), U44.7 (GND), U45.7 (GND); also elsewhere on the board

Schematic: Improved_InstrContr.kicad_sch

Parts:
U101, U102, U103, U104, U105: (no value)

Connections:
unnamed: U101.3, U105.3
unnamed: U101.4, U101.9, U103.3, U103.4
unnamed: U101.5, U102.4
unnamed: U101.6, U103.12, U105.13
unnamed: U101.7 (GND), U102.7 (GND), U103.7 (GND), U104.7 (GND), U105.7 (GND)
unnamed: U101.8, U104.8
unnamed: U101.10, U102.2
unnamed: U101.11, U104.2, U105.9
unnamed: U101.2, U101.12
unnamed: U101.13, U103.6
unnamed: U101.14 (VCC), U102.14 (VCC), U103.14 (VCC), U104.14 (VCC), U105.14 (VCC)
unnamed: U102.1, U103.2
unnamed: U102.5, U103.5
unnamed: U102.6, U103.13, U104.9
unnamed: U102.9, U102.10, U102.12, U102.13, U103.9, U103.10
unnamed: U103.11, U104.5
unnamed: U104.1, U104.11
unnamed: U104.4, U105.11
unnamed: U104.6, U105.1
unnamed: U104.10, U105.5

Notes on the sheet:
Ep = T1 Cp = T2 Li = T3 Lo = Ea = (OUT T4) Lb = (ADD + SUB) T5 Eu = (ADD + SUB) T6 Ei = (ADD + SUB + LDA) T4 Su = (SUB T6) CE = Lb + (LDA T5) + T3 La = Eu + (LDA T5) Lm = Ei + T1

Board: 2 copper layers, 176 parts (0 on the bottom side), 251 nets, no tracks yet.
